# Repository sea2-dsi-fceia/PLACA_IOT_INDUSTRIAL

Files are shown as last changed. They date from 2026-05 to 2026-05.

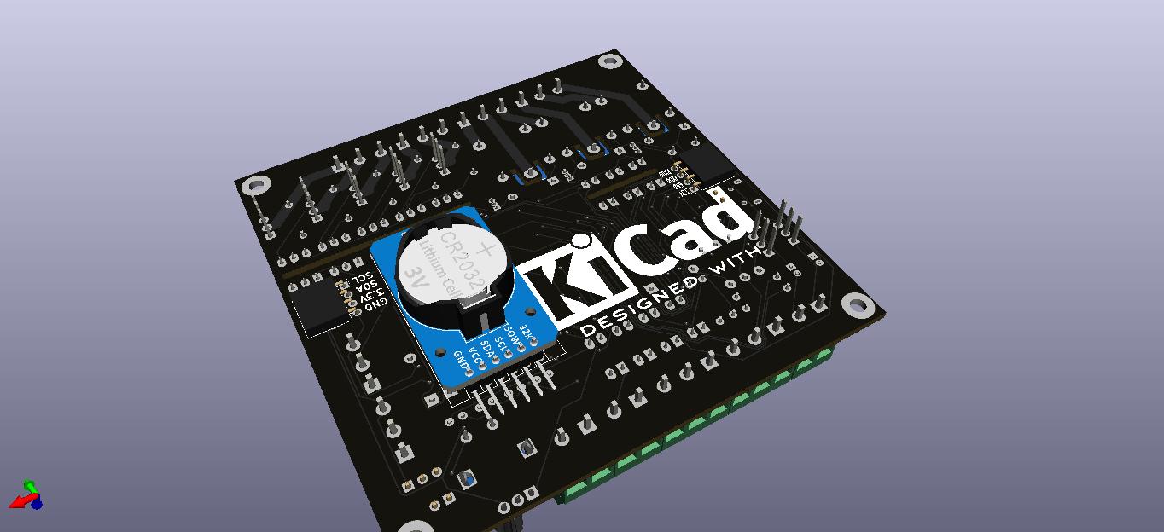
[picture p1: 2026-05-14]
Archivos_Kicad/Imagenes/PLC_ESP32_back.jpg

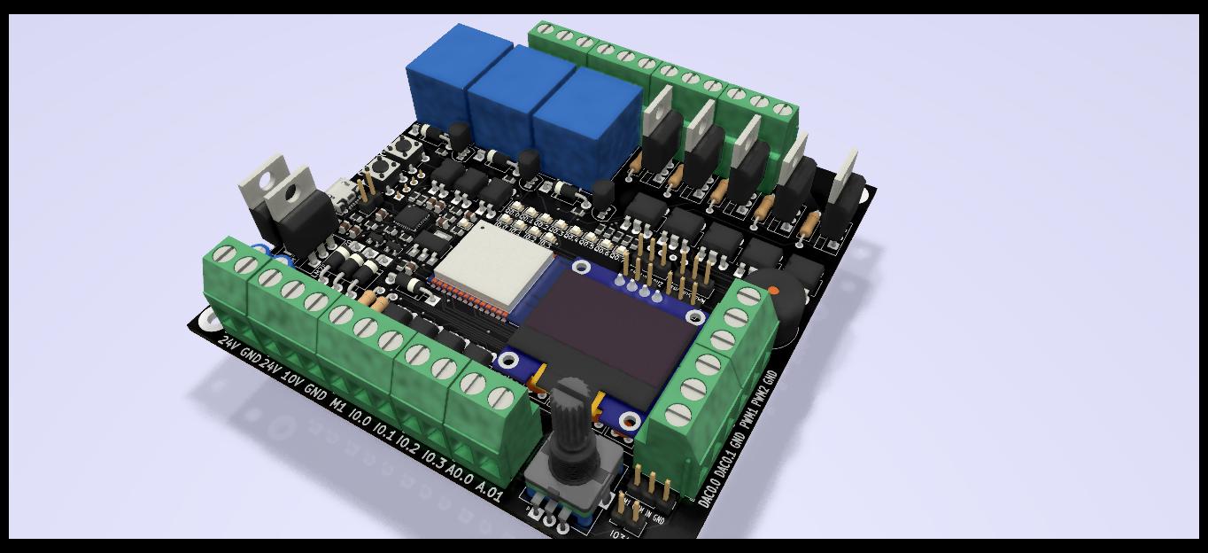
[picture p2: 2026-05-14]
Archivos_Kicad/Imagenes/PLC_ESP32.jpg

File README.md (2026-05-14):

## Placa de desarrollo IoT Industrial basada en ESP32
## 📝 Descripción
Este repositorio contiene el diseño y la documentación de una placa de desarrollo robusta diseñada para aplicaciones de Internet de las Cosas Industrial (IIoT), domótica y enseñanza de sistemas embebidos. El corazón del sistema es un microcontrolador ESP32 de Espressif, integrado en un hardware capaz de soportar entornos industriales exigentes. 
La placa permite gestionar lógica programada para actuar sobre cargas de potencia (electroválvulas, motores, actuadores) bajo condiciones específicas de trabajo.

## 🚀 Características Técnicas
### Alimentación y Entradas
- **Voltaje de alimentación:** Soporta niveles industriales entre 12V y 24V CC.  
- **Entradas Digitales (4):** Optoaisladas para protección del microcontrolador, con soporte de niveles entre 5V y 24V y LEDs testigos.
**NOTA:** Las entradas digitales deben tener configuradas en el ESP32 las resistencias de PULL-DOWN internas o agregar de forma externa resistencias de PULL-DOWN para que las etapas de entrada funcionen de forma correcta.
- **Entradas Analógicas (2):** Rango de 0V a 10V con alta impedancia. 

### Salidas de Potencia 
- **Salidas a Relé (3):** Relés de simple inversor optoaislados, con capacidad de manejo en 220V CA o 24V CC.  
- **Salidas de Estado Sólido (5):** Implementadas con TRIACs optoaislados (MOC3021 y BT136) para cargas de 220V CA. 
- **Protección:** Diodos de freewheeling (1N4007) en antiparalelo con las bobinas de los relés para proteger los transistores driver.

### Periféricos e Interfaz
- **Pantalla OLED:** Comandada por protocolo $I^{2}C$ para interfaz HMI local.  
- **Almacenamiento:** Memoria EEPROM para datos no volátiles.  
- **Tiempo Real:** Reloj calendario (RTC) con batería de backup para registro de eventos.  Indicadores: LED RGB y alarma sonora (buzzer) para monitoreo de estados.

## 🛠️ Diseño de Hardware
El PCB fue diseñado en KiCad priorizando la robustez y la facilidad de mantenimiento:
- **Aislamiento Galvánico:** Uso de optoacopladores PC817 para separar la lógica de las etapas de potencia.  
- **Seguridad Eléctrica:** Muescas de aislación en la placa alrededor de los conectores comunes de los relés para evitar arcos de voltaje en 220V CA.
- **Dimensionamiento:** Pistas trazadas en ambas capas (TOP y BOTTOM) para mejorar el manejo de corriente y evitar sobrecalentamiento.

## 💻 Desarrollo de Software
La placa es versátil en cuanto a paradigmas de programación:
- **Sistemas Operativos en Tiempo Real (RTOS):** Soporte nativo para FreeRTOS y Zephyr, garantizando tiempos de respuesta determinísticos ante eventos críticos.
- **Estándar Industrial:** Compatible con el proyecto OpenPLC, permitiendo programación en lenguaje Ladder bajo la norma IEC 61131-3.
- **Conectividad IIoT:** Implementación de protocolos como Modbus TCP, MQTT para telemetría, WebSockets y Webservers embebidos con interfaces HTML.  

## 📂 Ejemplo de Aplicación: Control de Caldera
El proyecto incluye un ejemplo integrador de un sistema de control de temperatura con seguridad por presión: 
- **Sensor:** Lectura de temperatura vía LM35 en entrada analógica.  
- **Seguridad:** Detección de alta presión mediante sensor digital que desactiva el calefactor y activa un ventilador de emergencia.  
- **Telemetría:** Monitoreo remoto mediante una webapp alojada en el propio microcontrolador.

## 📈 Roadmap y Mejoras Futuras
- Integración de puerto Ethernet nativo.  
- Implementación de buses de campo: RS-485 y CAN BUS.  
- Fuente de alimentación conmutada tipo Buck DC-DC para mayor eficiencia

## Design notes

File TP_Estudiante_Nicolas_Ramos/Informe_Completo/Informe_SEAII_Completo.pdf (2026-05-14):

## Universidad Nacional de Rosario

### Facultad de Ciencias Exactas, Ingeniería y Agrimensura

# Trabajo Práctico Integrador

Sistemas embebidos avanzados II

Alumno: RAMOS, Nicolás

Legajo: R-3892/1

Año: 2026

## Índice

### 1. Introducción

### 2. Validación de hardware placa de desarrollo

2.1 Objetivo y contexto

2.2 Descripción del hardware

2.3 Sketch de prueba

2.4 Herramientas de desarrollo

### 3. Etapa de modelado (UML)

3.1 Diagrama de casos de uso

3.2 Diagrama de actividad

3.3 Diagrama de despliegue

3.4 Diagrama de máquina de estados

3.5 Diagrama de componentes

3.6 Diagrama de secuencia

### 4. Etapa de implementación

4.1 Plataforma y herramientas

4.2 Estructura del proyecto y organización del código

4.3 Tareas y prioridades

4.4 Mecanismos de sincronización

4.5 Manejo de errores

4.6 Consideraciones de concurrencia

### 5. Conclusiones

### 6. Referencias y código fuente

4

## 1. Introducción

Este informe documenta de forma integrada el trabajo práctico desarrollado en la asignatura Sistemas Embebidos Avanzados II. El trabajo se organizó en dos etapas complementarias.

En la primera etapa se realizó el montaje de componentes sobre la placa de desarrollo para aplicaciones industriales IOT basada en ESP32 y la validación de hardware. El objetivo fue comprobar el correcto funcionamiento de entradas y salidas digitales, entradas analógicas, salidas DAC, display OLED, buzzer y periféricos asociados, antes de abordar el firmware más exigente en tiempo real.

En la segunda etapa se implementó un control de temperatura aplicado a una caldera, ejecutado sobre el sistema operativo en tiempo real FreeRTOS incluido en ESP-IDF. La información del proceso se presenta en un display OLED y en una página web servida por el propio microcontrolador, configurando el WiFi del ESP32 como punto de acceso (AP) para acceder sin depender de una red externa.

## 2. Validación de Hardware

### 2.1 Objetivo y contexto

El proyecto consistió en llevar a cabo el montaje de componentes, relevamiento del circuito esquemático y la validación de todas las etapas del circuito de forma individual. Una vez realizada dicha validación, se diseñó una plantilla para inicializar y configurar periféricos de la placa de desarrollo y una librería para el uso del display OLED, para ser usadas por futuros alumnos de la asignatura.

La placa incorpora periféricos útiles para automatización: entradas digitales y analógicas, salidas a relé y triacs, salidas PWM/DAC, display OLED por I²C, módulo RTC, buzzer y salidas de potencia. Para esta etapa se utilizó el IDE Arduino con el core ESP32, por la rapidez para compilar, flashear y probar cada recurso sin la sobrecarga inicial de un proyecto ESP-IDF completo.

5

### 2.2 Descripción del hardware

A continuación se resume la correspondencia entre recursos de la placa y GPIO del ESP32, coherente con el

sketch de validación PLC_ESP32_EntradasSalidas.ino.

### 2.2.1 Entradas digitales (I0.0 – I0.3)

Cuatro entradas digitales aisladas mediante optoacopladores, conectadas a GPIO del ESP32. En las pruebas se habilitaron pull-down internas.

Entrada | GPIO ESP32
I0.0 | 5
I0.1 | 15
I0.2 | 16
I0.3 | 34

Tabla 1 — Entradas digitales y GPIO.

### 2.2.2 Salidas digitales (Q0.0 – Q0.7)

Tres salidas a relés (Q0.0–Q0.2) y cuatro salidas a triacs (Q0.3–Q0.7), con etapas de acoplamiento.

Salida | GPIO ESP32
Q0.0 | 4
Q0.1 | 17
Q0.2 | 18
Q0.3 | 19

6

Salida | GPIO ESP32
Q0.4 | 23
Q0.5 | 27
Q0.6 | 32
Q0.7 | 33

Tabla 2 — Salidas digitales y GPIO.

### 2.2.3 Entradas analógicas (A0.0 – A0.1)

Entrada | GPIO
A0.0 | 36
A0.1 | 35

Tabla 3 — Entradas analógicas.

### 2.2.4 Salidas DAC (DAC0.0 – DAC0.1)

Salida | GPIO
DAC0.0 | 25
DAC0.1 | 26

Tabla 4 — Salidas DAC del ESP32.

### 2.2.5 Display OLED (I²C)

Display compatible con controlador SH1106, típicamente 128×64, dirección I²C 0x3C, SDA GPIO 21 y SCL

7

GPIO 22.

### 2.2.6 Buzzer y LED RGB

Buzzer en GPIO 2. LED RGB (cátodo común): R=14, G=13, B=12, según definiciones del sketch de validación.

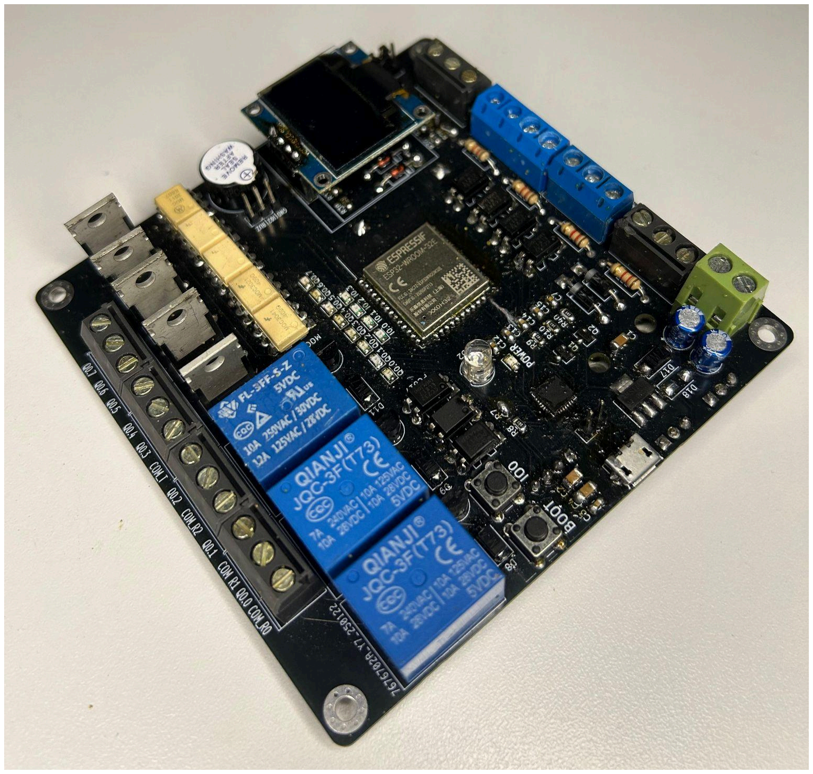
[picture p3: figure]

Figura 1. Placa de desarrollo para aplicaciones industriales IoT basada en ESP32

### 2.3 Sketch prueba de hardware

Con el programa de ejemplo se verificó, entre otros puntos:

- Entradas digitales I0.0–I0.3: lectura coherente en reposo y al activar cada entrada, con pull-down internas habilitadas.
- Entradas Analógicas A0.0–A0.1: lectura con analogRead y envío por puerto serie para correlacionar tensión aplicada (0–3,3 V) con el valor digital.
- Salidas digitales Q0.0–Q0.7: conmutación secuencial e individual; coherencia entre estado lógico y actuación sobre LED, relé o carga de prueba.

8

- Salidas DAC: uso de dacWrite y comprobación con multímetro.
- OLED: inicialización con librería Adafruit SH110X; texto y actualización periódica.
- Buzzer: conmutación periódica del pin para verificar audio; puede extenderse con tone().

### 2.4 Herramientas de desarrollo

- IDE Arduino con soporte ESP32, para el sketch PLC_ESP32_EntradasSalidas.ino.
- Cable USB y monitor serie para depuración y registro de valores analógicos.

## 3. Etapa de modelado (UML)

En esta parte del trabajo práctico se trabajó en un control de temperatura aplicado a una caldera, basado en sistema operativo en tiempo real, con varias actividades concurrentes, recursos compartidos y restricciones temporales.

Antes de escribir o integrar el firmware definitivo, se necesitó disponer de un modelo formal del sistema. Para ello, se utilizó como lenguaje común entre requisitos, diseño e implementación, el lenguaje UML (Unified Modeling Language). El modelado obliga a nombrar actores, límites del sistema, secuencias de interacción, estados discretos del control y piezas de software que deben coexistir bajo el planificador. A continuación se mostrarán los diagramas correspondientes para describir la lógica y dinámica del sistema, arquitectura del software y disposición del hardware.

9

### 3.1 Diagrama de casos de uso

El diagrama de casos de uso presenta el sistema embebido como una caja negra y enumera las capacidades visibles desde el exterior, sin entrar en tareas ni mutex. El límite del sistema (system boundary) encierra al controlador sobre la placa de desarrollo.

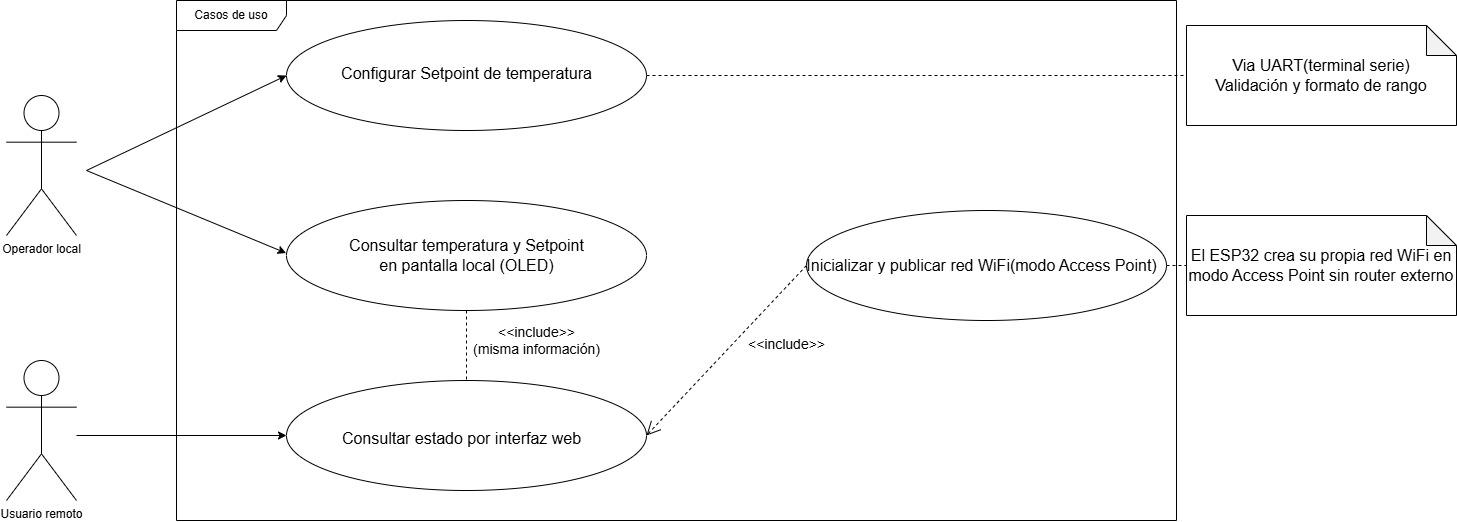
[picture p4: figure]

Figura 2. Diagrama Casos de Uso

10

### 3.2 Diagrama de actividad

El diagrama de actividad describe flujos de control con decisiones, bifurcaciones y actividades que pueden ser paralelas o secuenciales.

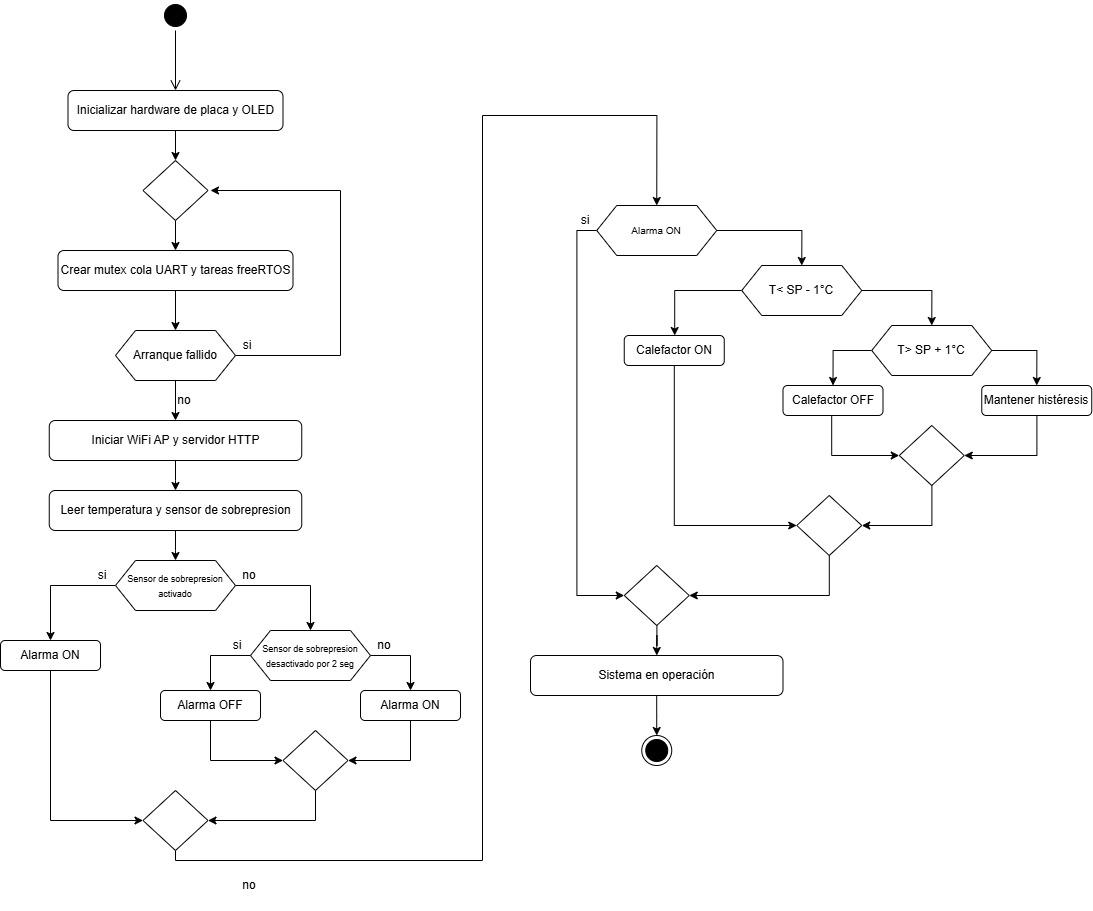
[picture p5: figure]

Figura 3. Diagrama de actividad

11

### 3.3 Diagrama de despliegue

Este diagrama se utiliza para modelar la arquitectura física de un sistema. Su objetivo principal es mostrar cómo se distribuyen los componentes de software en los recursos de hardware (como servidores, computadoras o dispositivos móviles) durante el tiempo de ejecución

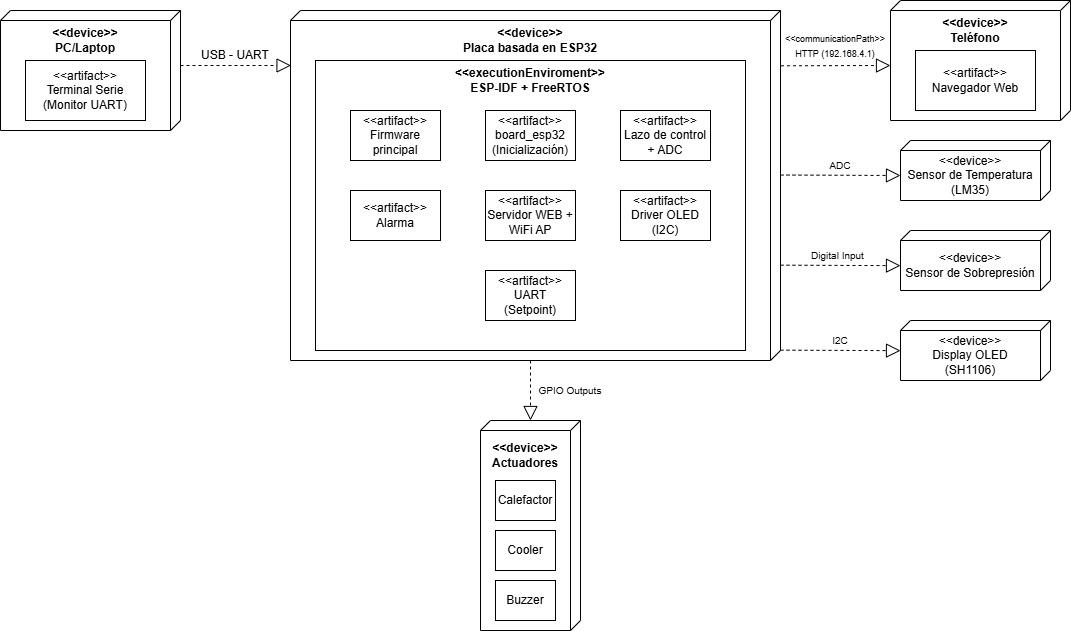
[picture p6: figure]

Figura 4. Diagrama de despliegue

12

### 3.4 Diagrama Máquinas de Estado

Este diagrama describe cómo se comporta un objeto específico o un sistema entero basándose en su historial de eventos. El sistema posee al menos dos estados lógicos dominantes: Normal y Alarma por sobrepresión. En Normal, la calefacción sigue una lógica con histéresis alrededor del setpoint y el cooler permanece desactivado salvo políticas adicionales no usadas aquí. En Alarma, la calefacción queda forzada a apagarse, el cooler se activa, el buzzer se activa de forma intermitente y las interfaces muestran un mensaje de advertencia.

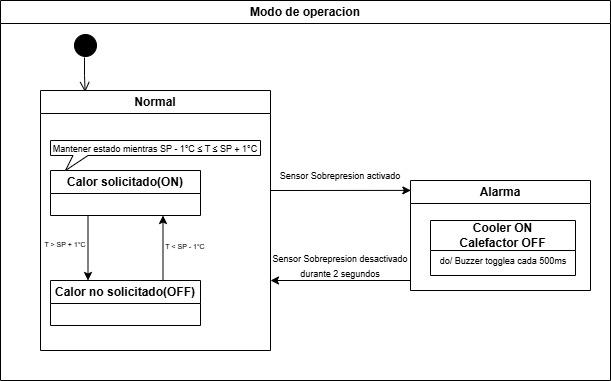
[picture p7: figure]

Figura 5. Diagrama de Máquinas de Estado

13

### 3.5 Diagrama de componentes

El diagrama de componentes muestra la arquitectura de software y las dependencias entre piezas, alineado con lo que luego se implementará como archivos y tareas.

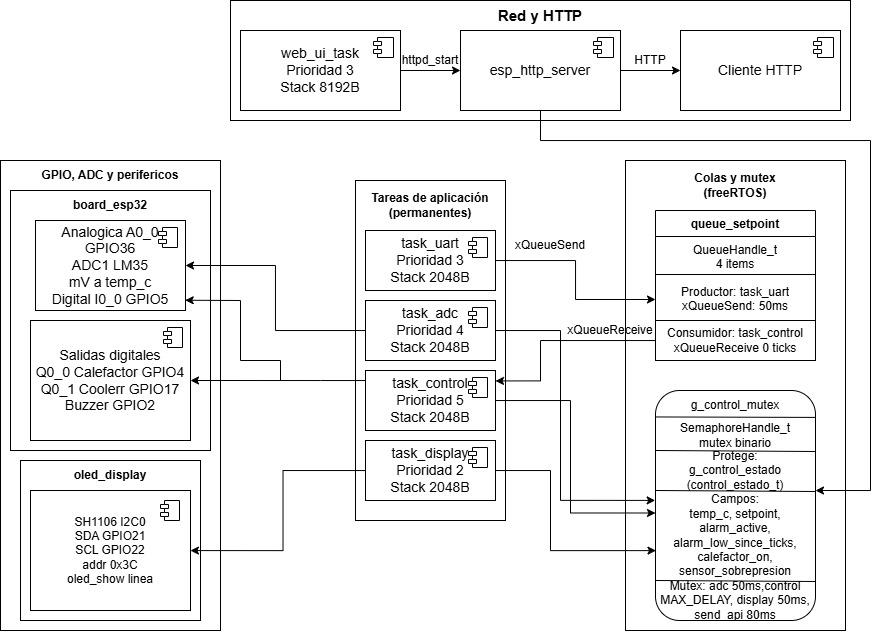
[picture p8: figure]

Figura 6. Diagrama de componentes

Entre estos componentes aparecen interfaces de FreeRTOS: una cola de mensajes para transportar enteros de setpoint desde la UART hacia el control; un mutex asociado a la estructura de estado compartido que deben

14 respetar la adquisición, el control, la vista OLED y el endpoint JSON. El diagrama debe mostrar que el servidor HTTP depende del mismo tipo de datos que la tarea de display, pero no debe dibujarse como si el HTTP escribiera directamente temperatura: en la implementación, el HTTP solo lee una copia bajo mutex. Las flechas de dependencia van desde las tareas o componentes de aplicación hacia los drivers de ESP-IDF (UART, GPIO, ADC, esp_wifi, esp_http_server), indicando que el firmware de aplicación se apoya en el framework.

### 3.6 Diagrama de secuencia

Es un diagrama de comportamiento que modela la interacción lógica entre objetos, enfocándose específicamente en el orden temporal en el que se intercambian mensajes para ejecutar una funcionalidad o escenario concreto. A diferencia de los diagramas estáticos (como el de clases de uso), este es dinámico: describe cómo "vive" y se comunica el sistema paso a paso durante un proceso.

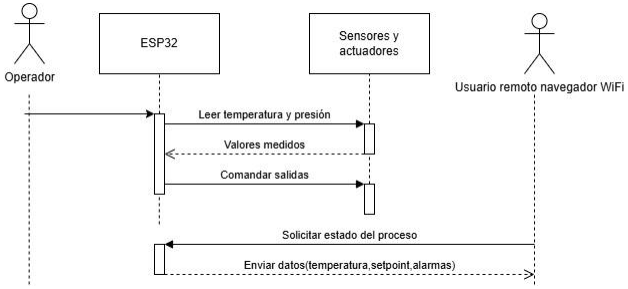
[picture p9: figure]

Figura 7. Diagrama de secuencia

15

## 4. Etapa de implementación

### 4.1 Plataforma y herramientas

La implementación del proyecto se basa en una placa de desarrollo equipada con el microcontrolador ESP32. Para su programación se utilizó el framework oficial del fabricante ESP-IDF, el cual integra el kernel del sistema operativo en tiempo real FreeRTOS y pone a disposición toda su API (tareas, colas, semáforos, mutex). El flujo de trabajo se gestionó a través del entorno Visual Studio Code con la extensión ESP-IDF, permitiendo compilar, flashear y monitorear el dispositivo por el puerto serial (UART0, vía USB). La UART0 queda reservada para la configuración del setpoint.

Para esta parte del trabajo práctico, se recurrió a la herramienta Cursor el cual es un entorno de programación basado en Visual Studio Code que integra asistencia con modelos de lenguaje (inteligencia artificial) para tareas como completar código, explicar fragmentos y apoyar la revisión de errores de compilación o de sintaxis. En ningún caso se delegó el criterio de diseño ni la responsabilidad del trabajo al asistente, el uso fue incremental y supervisado, es decir, se le indicaron objetivos concretos, se corrigió o descartó lo que no encajaba con el enunciado o con el hardware real, y se fue guiando el resultado (prioridades de tareas, sincronización con mutex y colas, comportamiento de alarmas, etc.) hasta alinearlo con lo implementado en el firmware y con lo exigido por la asignatura. Básicamente su uso sirvió para optimizar tiempos de codificación, por ejemplo en la estructuración de módulos y partes repetitivas del código, pero el contenido técnico, las decisiones y la verificación quedaron a mi cargo.

### 4.2 Estructura del proyecto y organización del código

El proyecto se organiza en módulos con responsabilidades bien definidas. A continuación presento los archivos y su función dentro del proyecto:

ESP32_FreeRTOS: Archivo principal del firmware. Contiene el punto de entrada app_main(), la definición de la estructura de estado compartido (estado_t), el mutex y la cola, las constantes de prioridad y tiempos, las

16 cuatro tareas: task_adc, task_uart, task_control, task_display, y web_ui_start(). Incluye además la función auxiliar leer_temperatura_lm35() que convierte la lectura del ADC a temperatura en °C.
board_esp32.c: Implementación de la capa de entradas/salidas. Configuración de GPIOs y ADC1.

board_esp32.h: Cabecera del módulo board_esp32. Define los números de GPIO para todas las entradas y salidas.

oled_display.c: Driver del display OLED SH1106 por I2C. Implementa inicialización del bus I2C (SDA y SCL), secuencia de inicio del SH1106, y las funciones oled. Utiliza una fuente 6×8 para mostrar texto centrado en una línea.

oled_display.h: Cabecera del módulo OLED. Define pines I2C, dirección del dispositivo (0x3C), dimensiones del display y declara las funciones públicas.

control_state.c: Implementación mínima del módulo. Inicializa g_control_estado con valores por defecto (setpoint, flags), aquí no se crea el mutex, sólo concentra el dato compartido del sistema.

control_state.h: Cabecera del estado compartido del control. Define el struct control_estado_t (temperatura, setpoint, alarma, flags y sobrepresión), y declara variables globales g_control_estado y el handle g_control_mutex para que las tareas y el HTTP las usen de forma coherente.

web_ui.c: Implementa el modo WiFi AP (NVS, netif, credenciales), arranca httpd con las rutas /html y el /api/status (JSON leyendo el estado bajo mutex) y crea la tarea web_ui_task que hace el init y luego se elimina mientras el servidor sigue activo.

web_ui.h: Cabecera del servidor web embebido. Declara la función de arranque web_ui_start para levantar el punto de acceso WiFi y el servidor HTTP.

### 4.3 Tareas y prioridades

Las tareas de aplicación son hasta cinco: cuatro se crean con xTaskCreate en app_main() (la de UART sólo si el driver instaló bien) y la quinta, web_ui_task, se crea dentro de web_ui_start() llamada desde app_main(). Las cuatro tareas periódicas corren en bucle infinito y ceden el CPU con vTaskDelay, mutex o cola/UART bloqueante; web_ui_task ejecuta la secuencia de arranque de red y HTTP y termina con vTaskDelete.

17

Tarea de adquisición de temperatura (task_adc)
Su función es mantener actualizado el valor de temperatura del proceso en la estructura de estado compartido, a partir de la lectura periódica del canal analógico A0.0 conectado al sensor LM35. No actúa sobre periféricos de salida, sólo escribe el campo temp_c del estado_t. En cada iteración la tarea intenta tomar el mutex con un timeout de 50 ms. Si lo obtiene, escribe la temperatura recién leída en estado.temp_c y libera el mutex de inmediato; en caso contrario omite la actualización en ese ciclo. A continuación ejecuta vTaskDelay(200 ms), con lo que cede el procesador y fija el período efectivo de muestreo en 200 ms.
La tarea se ejecuta en un bucle infinito. No mantiene estado local entre iteraciones más allá de la variable de temperatura leída. Ante fallo del ADC, leer_temperatura_lm35() retorna 0.0 °C, por lo que la tarea sigue actualizando el estado sin bloquear el sistema.

Tarea de recepción de setpoint por UART (task_uart)
Su función es encargarse de recibir por UART0 los setpoints que envía el operador desde un terminal o adaptador serial. Funciona en un bucle continuo y, en cada iteración, lee un solo byte de forma bloqueante (portMAX_DELAY), porque el enlace USB suele entregar los caracteres de a uno y leer bloques fijos de dos bytes no es fiable. Esos caracteres se van acumulando en un buffer interno hasta detectar un fin de línea (\r o \n). En ese momento se interpreta la línea: si contiene exactamente un dígito ASCII entre '0' y '9', el setpoint resultante es ese valor (0–9); si tiene al menos dos caracteres y los dos primeros son dígitos, se forma el número en decimal como decenas × 10 más unidades y se acota al rango 0–99 (valores mayores a 99 se consideran 99). Cualquier otra forma de línea al pulsar Enter no produce un envío a la cola. Cuando hay un setpoint válido, la tarea lo pone a disposición de task_control mediante xQueueSend sobre la cola de FreeRTOS, sin usar mutex, ya que la API de colas serializa de forma segura el paso de mensajes entre tareas. Si la cola está llena, la llamada espera como máximo 50 ms; si en ese intervalo no se pudo encolar, el intento falla, el valor de esa línea no se conserva para un reenvío posterior y la tarea sigue ejecutándose sin quedar bloqueada indefinidamente. La tarea no modifica el setpoint por defecto del sistema ni escribe directamente el estado compartido: solo aporta nuevos valores cuando el operador envía explícitamente una línea válida por UART0, y es task_control quien incorpora esos valores a partir de lo recibido por la cola.

18

Tarea de control (task_control)
Esta tarea concentra la lógica del lazo de temperatura y de la máquina de estados asociada a la sobrepresión leída en I0.0. En cada ciclo, primero intenta incorporar un nuevo setpoint desde la cola FreeRTOS con xQueueReceive y tiempo de espera nulo, de modo que no bloquee si no hay mensajes pendientes. A continuación toma el mutex g_control_mutex con portMAX_DELAY, es decir, espera el tiempo que haga falta hasta entrar en la sección crítica, y no hay un segundo bloqueo ni timeouts cortos dedicados al setpoint. Dentro de esa misma sección se lee la temperatura ya publicada en el estado global, se interpreta I0.0 según la polaridad configurada (PRESION_I0_ACTIVO_NIVEL_ALTO), se actualiza el indicador de alarma activa (entrada inmediata cuando la presión indica falla y salida solo tras 2000 ms continuos con I0.0 en el nivel “inactivo”), se escribe setpoint en el estado compartido para que la tarea de display y la interfaz web muestren el valor vigente, y se calcula el pedido de calefacción con histéresis respecto del setpoint, salvo en alarma, donde se anula la retención del calefactor. Tras xSemaphoreGive, fuera de la sección crítica, se aplican las salidas físicas: en alarma se apaga Q0.0(calefactor), se enciende Q0.1(cooler) y se hace togglear el buzzer con un período fijo; en operación normal se apagan cooler y buzzer y se activa Q0.0 según el resultado del control con histéresis. El ritmo del lazo queda acotado por vTaskDelay(100 ms) al final de cada iteración.

Tarea de presentación en display (task_display)
Esta tarea cumple una función exclusivamente de interfaz humano - máquina: pone a disposición del operador, en el display OLED, la información esencial del proceso, la temperatura medida, el setpoint vigente y la condición de alarma de sobrepresión. Cuando la alarma está activa, el mensaje se reduce a una leyenda fija de Sobrepresión; en operación normal se arma una cadena con temperatura y setpoint y se envía al driver del OLED. Para obtener esos datos sin mezclar lecturas parciales con escrituras concurrentes de otras tareas, la rutina toma el mutex con un timeout de 50 ms, copia en variables locales la temperatura, el setpoint y el flag de alarma, y libera de inmediato el mutex. Ejecuta el trabajo más lento —formateo de texto y actualización del display vía I2C— fuera de la sección crítica, lo que mantiene acotado el tiempo en que el mutex está tomado y reduce la interferencia con tareas que actualizan el mismo estado global. Si en un ciclo no se consigue el mutex dentro del plazo de espera, la tarea no refresca el OLED en esa pasada, aplica un vTaskDelay de 200

19 ms y vuelve a intentar en la siguiente vuelta del bucle, evitando bloqueos indefinidos. Tras una actualización exitosa del display, el ritmo queda marcado por un vTaskDelay de 500 ms, de modo que la presentación se renueva aproximadamente dos veces por segundo. La tarea no modifica el estado del control ni las salidas de campo; se limita a leer el estado compartido y a reflejarlo en pantalla.

Tarea de interfaz web (web_ui_task)
Es la encargada de poner en marcha la interfaz web del proyecto. Se crea desde web_ui_start() con prioridad 3 y un stack de 8192 Bytes, pensada para absorber el consumo de memoria del init de WiFi en modo punto de acceso (NVS, esp_netif, bucle de eventos, configuración del AP con SSID y contraseña fijos) y la creación del servidor HTTP del ESP-IDF. En la práctica, la rutina inicializa el AP, espera 500 ms para dejar estabilizar la interfaz de red y llama a httpd_start, registrando dos URL: la raíz que sirve la página HTML embebida con estilos y un script que consulta periódicamente el estado, y /api/status, que responde en JSON con temperatura, setpoint, estado del calefactor, lectura lógica de sobrepresión y bandera de alarma. El handler de la API toma el mutex con un timeout de 80 ms, copia la estructura g_control_estado a una variable local y libera el mutex antes de formatear y enviar la respuesta; si el mutex no está disponible a tiempo, devuelve 503(servicio no disponible) con un cuerpo mínimo, evitando bloquear indefinidamente al cliente y evitando servir datos inconsistentes. Al terminar el arranque, la tarea se autoelimina con vTaskDelete(NULL), el portal sigue atendido por las tareas internas del stack HTTP de Espressif, mientras que web_ui_task ya no permanece en un bucle periódico como las tareas de ADC, control o display.
TAREA | PRIORIDAD | PERIODO O CONDICIÓN | STACK
task_control | 5 | Cada 100 ms | 2048B
task_adc | 4 | Cada 200 ms | 2048B
task_uart | 3 | Bloqueada en uart_read_bytes hasta recibir un carácter (portMAX_DELAY) | 2048B
task_display | 2 | Cada 500 ms | 2048B

20

web_ui_task | 3 | Un solo arranque: WiFi AP + httpd_start, luego vTaskDelete (no periódica)”.

8192B

### 4.4 Mecanismos de sincronización

Estructura de estado compartido
- La variable global es g_control_estado, de tipo control_estado_t. typedef struct {
float | temp_c; /* Temperatura medida en °C*/
int | setpoint; /*Consigna en °C*/
bool | alarm_active; /*Estado alarma*/
TickType_t alarm_low_since_ticks; /*Marca de ticks con I0.0 activada para salir de modo Alarma*/
bool | calefactor_on;
bool | sensor_sobrepresion;
} control_estado_t;
- task_adc escribe sólo temp_c.
- task_control lee temp_c y el estado de alarma. Actualiza alarm_active, alarm_low_since_ticks, setpoint, calefactor_on y sensor_sobrepresion.
- task_display sólo lee temp_c, setpoint y alarm_active para el OLED.
- El handler send_api en web_ui.c copia bajo mutex toda la estructura a una variable local st de tipo control_estado_t para armar el JSON.

Todo acceso a g_control_estado debe realizarse con el mutex tomado.

Mutex (g_control_mutex)
El mutex actúa como candado, sólo una tarea puede poseerlo a la vez.
Uso: xSemaphoreTake(g_control_mutex, timeout) → acceso a g_control_estado → xSemaphoreGive(g_control_mutex).

21

Timeouts: 50 ms (task_adc, task_display), portMAX_DELAY (task_control) y 80 ms en send_api(si no obtiene el mutex, responde 503).

Cola (queue_setpoint)
Es un buffer FIFO de FreeRTOS que transporta setpoints como enteros int en el rango 0–99 (tras la validación en task_uart) desde task_uart hasta task_control, sin que la UART escriba directamente en g_control_estado.

Se declara como QueueHandle_t estático en ESP32_FreeRTOS.c y se crea con xQueueCreate(SETPOINT_QUEUE_LEN, sizeof(int)), donde SETPOINT_QUEUE_LEN vale 4: hasta cuatro mensajes pendientes.

task_uart: envía con xQueueSend(queue_setpoint, &setpoint, pdMS_TO_TICKS(50)). Si la cola está llena, espera como máximo 50 ms; si en ese plazo no pudo encolar, ese valor no se guarda para un reintento automático.

task_control: al inicio de cada ciclo hace xQueueReceive(queue_setpoint, &nuevo_setpoint, 0), el 0 indica sin espera, es decir no bloqueante.Si no hay mensaje nuevo, sigue con el setpoint local que ya tenía.

Las operaciones xQueueSend / xQueueReceive sobre la misma cola están pensadas para uso concurrente entre tareas en FreeRTOS: el kernel serializa el acceso a la cola, de modo que no hace falta un mutex adicional solo para encolar o desencolar el setpoint entre task_uart y task_control.

22

### 4.5 Manejo de errores

SITUACIÓN | DÓNDE SE DETECTA | ACCIÓN | EFECTO
Fallo al crear mutex (g_control_mutex) o cola (queue_setpoint) | app_main() tras xSemaphoreCreateMutex() / xQueueCreate() | return (sin log en ese if) | No se ejecutan xTaskCreate ni web_ui_start(): el lazo de tareas no arranca.
Fallo uart_driver_install en UART0 (USB, setpoint) | app_main() | No se llama xTaskCreate(task_uart, …); el resto de tareas sí se crean | No hay entrada de setpoint por terminal; task_control mantiene SETPOINT_DEFAULT (25 °C) hasta otra vía.
Fallo al crear unidad ADC1 | board_esp32_init() (adc_oneshot_new_unit ≠ ESP_OK) | adc1_handle = NULL | board_esp32_adc_a0_0 _mv() devuelve -1; leer_temperatura_lm35() puede quedar con n = 0 y devuelve 0.0 °C; el lazo puede reaccionar mal si se interpreta como “muy frío”.
Fallo calibración ADC | board_esp32_init() (adc_cali_create_scheme_line_f itting ≠ ESP_OK) | adc1_cali_a0 = NULL | Sigue habiendo lectura por conversión aproximada raw→mV; peor precisión, no bloquea el arranque.
Cola queue_setpoint llena al enviar setpoint | task_uart en xQueueSend(..., pdMS_TO_TICKS(50)) | El resultado se ignora con (void) | Ese setpoint se pierde; el operador debe reenviar el comando.
Timeout al tomar g_control_mutex (50 ms) | task_adc | No escribe g_control_estado.temp_c en ese ciclo | La temperatura mostrada/controlada puede quedar desactualizada hasta el próximo ciclo exitoso.

23

Timeout al tomar g_control_mutex (50 ms) | task_display | vTaskDelay(200 ms) y continue | No se actualiza el OLED en esa pasada; reintento después del delay.
g_control_mutex nulo o timeout (80 ms) al tomar mutex | send_api (web_ui.c) | Responde 503 | El navegador no recibe JSON de estado en esa petición (el script puede dejar valores viejos).
Fallo I2C en init del OLED | oled_display_init() | return antes de marcar éxito; oled_initialized permanece false (sin ESP_LOGE en esas líneas) | Display inoperativo hasta que otra llamada (p. ej. oled_show) reintente oled_display_init().
Fallo httpd_start | http_start() en web_ui.c | ESP_LOGE y return sin registrar URI | WiFi AP puede estar activo pero sin página / ni API /api/status útiles.
Fallos en init WiFi/NVS con ESP_ERROR_CHECK | wifi_init_ap() en web_ui.c | En IDF suele abortar el programa con mensaje de error | Reinicio o detención según configuración del proyecto; no es un fallo “silencioso” como el return de app_main.

### 4.6 Consideraciones de concurrencia

En este firmware varias actividades compiten por los mismos datos y recursos: las tareas task_adc, task_control y task_display, junto con los handlers HTTP del servidor en web_ui, pueden ejecutarse de forma entrelazada según el scheduler de FreeRTOS. Para evitar esto, todas las lecturas y escrituras de g_control_estado pasan por el mismo mutex g_control_mutex, con tiempos de espera acotados donde la interfaz puede ceder (50 ms en ADC y display, 80 ms en la API) y portMAX_DELAY en task_control, priorizando que el lazo y la lógica de alarma sigan actualizándose de forma predecible. El setpoint que llega

24 por UART no se escribe directamente en el estado compartido: task_uart solo encola enteros en queue_setpoint, y task_control los consume sin bloquear (xQueueReceive con espera cero), de modo que la recepción y validación del setpoint por UART0 no retiene el mutex ni prolonga la sección crítica del control. Las salidas físicas (GPIO de relés, cooler y buzzer) se actualizan después de liberar el mutex, reduciendo el tiempo en que otras tareas quedan bloqueadas esperando el mutex mientras se completan escrituras lentas a hardware. Las operaciones sobre la cola usan la API thread-safe del kernel, sin mutex adicional entre productor y consumidor del setpoint. Conviene tener presente que misma prioridad (por ejemplo task_uart y web_ui_task con prioridad 3) implica reparto por round-robin(se alternan), y que un handler HTTP que tardara demasiado podría retrasar a otras tareas de igual prioridad; el diseño actual limita el trabajo bajo mutex a copias breves de estructura y deja el formato JSON fuera de la sección crítica para mitigar ese riesgo.

25

## 5. Conclusiones

Este trabajo práctico atravesó las etapas típicas del desarrollo de un sistema embebido: primero con el montaje en PCB y validación de hardware se pudo asegurar el correcto funcionamiento de la placa, de modo que los problemas posteriores durante la implementación de software sean atribuidos a dicha etapa y no a fallas de cableado o periféricos.
A partir de este punto, la segunda parte, comenzando por el modelado con UML, ayudó a ordenar actores, responsabilidades, flujos de datos y estados, antes de comenzar con la programación propiamente dicha. Eso redujo ambigüedades sobre quien lee o escribe, temperatura, setpoint, alarma y salidas, y cómo se relacionan el operador, la UART, el display, la web y el lazo de control. En la implementación, esas decisiones se tradujeron en un diseño con varias tareas y prioridades, mutex sobre un estado compartido, y cola para el setpoint, además de temporizaciones y políticas de error acotadas. Se consolidó así la idea de concurrencia segura, donde el scheduler puede intercalar tareas, pero el acceso ordenado a datos y el paso de mensajes evitan condiciones de carrera y acoplamientos frágiles entre módulos.

Otro aprendizaje fue entender el uso del freeRTOS frente a bare-metal: en éste suele predominar un bucle principal e interrupciones, lo que complica atender tareas que deben ejecutarse con frecuencias distintas (muestreo, control, interfaz, red) sin que una parte bloquee otras y empuja a un estado global difícil de mantener. Con freeRTOS, la aplicación se organiza en tareas concurrentes con su período o bloqueo en E/S, el handler reparte el CPU según prioridad, y primitivas como mutex y colas estructuran al paralelismo lógico. El costo es mayor complejidad conceptual (sincronización, stacks, depuración de interacciones), pero el beneficio es un firmware más modular, escalable y alineado con sistemas industriales reales donde conviven control, comunicación e interfaz.

Por último, el uso de herramientas como Cursor resultó práctico para acelerar tiempos de codificación y corregir errores de sintaxis, pero no sustituye de ninguna manera el criterio del alumno, hubo que supervisar y rectificar constantemente nombres, tiempos, salidas incorrectas, asignaciones de prioridades, entre otras cosas. En un trabajo de ingeniería, la IA es una herramienta auxiliar, pero la responsabilidad del modelo, de la implementación y de la coherencia entre ambos sigue siendo del equipo que desarrolla y valida el sistema.

26

## 6. Referencias y código fuente

1. Espressif Systems. ESP-IDF Programming Guide. Documentación oficial ESP-IDF (build, FreeRTOS, WiFi, HTTP server). https://docs.espressif. com/projects/esp-modbus/en/latest/esp32/
2. FreeRTOS. Mastering the FreeRTOS Real Time Kernel — referencia de planificación, mutex, colas y buenas prácticas. https://www.freertos.org/Documentation/02-Kernel/07-Books-and-manual/01-RTOS_book.
3. Repositorio Proyecto_Final (archivos ESP32_FreeRTOS.c, web_ui.c, board_esp32.c, oled_display.c, control_state.c). https://github.com/nicojramos/Trabajo_Integrador_SEAII
4. UML-Diagrams.org, “Uml diagrams reference.” https://www.uml-diagrams.org/.

27

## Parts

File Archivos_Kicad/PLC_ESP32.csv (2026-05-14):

Reference | Quantity | Value | Footprint | Datasheet
BZ1 | 1 | Buzzer | Buzzer_Beeper:Buzzer_12x9.5RM7.6 | ~
C10 | 1 | 0.33uf | Capacitor_THT:CP_Radial_D5.0mm_P2.00mm | ~
C11 | 1 | 0.1uf | Capacitor_THT:CP_Radial_D5.0mm_P2.00mm | ~
C12 C13 C14 C15 | 4 | 100nf | Capacitor_THT:C_Disc_D5.0mm_W2.5mm_P2.50mm | ~
C2 | 1 | 47uf/6.3V(10%) | Capacitor_SMD:C_0805_2012Metric | ~
C3 C8 C9 C7 C5 | 5 | 0.1uf/50V(10%) | Capacitor_SMD:C_0805_2012Metric | ~
C4 C1 C6 | 3 | 22uF/10V(20%) | Capacitor_SMD:C_0805_2012Metric | ~
D1 | 1 | LED RED | LED_THT:LED_D3.0mm | ~
D19 D20 D22 D24 | 4 | LED | LED_THT:LED_D3.0mm | ~
D2 D3 D4 | 3 | LESD5D5.0CT1G |  | ~
D21 D23 | 2 | 1N4728A/3.3V | Diode_THT:D_DO-41_SOD81_P10.16mm_Horizontal | https://www.vishay.com/docs/85816/1n4728a.pdf
D5 | 1 | BAT760-7 30V 1A | Diode_THT:D_DO-41_SOD81_P10.16mm_Horizontal | ~
D6 D7 D10 D13 D14 D15 D16 D12 | 8 | LED | LED_SMD:LED_0805_2012Metric | ~
D8 D9 D11 D17 D18 | 5 | 1N4007 | Diode_THT:D_DO-41_SOD81_P10.16mm_Horizontal | http://www.vishay.com/docs/88503/1n4001.pdf
J1 | 1 | USB_B_Micro | BorneraTornillos:Conn_USBmicro-B_ebay-side_TH | ~
J10 | 1 | Salidas Analogicas | BorneraTornillos:TerminalBlock_Phoenix_PT-1,5-3-5.0-H_1x03_P5.00mm_Horizontal | ~
J11 | 1 | Salida PWM | BorneraTornillos:TerminalBlock_Phoenix_PT-1,5-3-5.0-H_1x03_P5.00mm_Horizontal | ~
J12 | 1 | UART_SERIE | Connector_PinSocket_2.54mm:PinSocket_1x04_P2.54mm_Vertical | ~
J13 J14 | 2 | Entrada Digital | BorneraTornillos:TerminalBlock_Phoenix_PT-1,5-3-5.0-H_1x03_P5.00mm_Horizontal | ~
J15 | 1 | Entrada Digital | BorneraTornillos:TerminalBlock_Phoenix_PT-1,5-2-5.0-H_1x02_P5.00mm_Horizontal | ~
J16 | 1 | Entrada Analogica | BorneraTornillos:TerminalBlock_Phoenix_PT-1,5-2-5.0-H_1x02_P5.00mm_Horizontal | ~
J2 J3 | 2 | Terminales Reles | BorneraTornillos:TerminalBlock_Phoenix_PT-1,5-3-5.0-H_1x03_P5.00mm_Horizontal | ~
J4 J5 | 2 | Terminales Triacs | BorneraTornillos:TerminalBlock_Phoenix_PT-1,5-3-5.0-H_1x03_P5.00mm_Horizontal | ~
J6 | 1 | Entrada_24VDC | BorneraTornillos:TerminalBlock_Phoenix_PT-1,5-2-5.0-H_1x02_P5.00mm_Horizontal | ~
J7 | 1 | PANTALLA LCD I2C | Connector_PinSocket_2.54mm:PinSocket_1x04_P2.54mm_Horizontal | ~
J8 | 1 | DS3231 | BorneraTornillos:DS3231_Shield | ~
J9 | 1 | PANTALLA OLED | Connector_PinSocket_2.54mm:PinSocket_1x04_P2.54mm_Vertical | ~
JP1 | 1 | Habilitacion VBUS | Connector_PinHeader_2.54mm:PinHeader_1x02_P2.54mm_Vertical | ~
JP2 | 1 | Comun Entradas | Connector_PinHeader_2.54mm:PinHeader_1x03_P2.54mm_Vertical | ~
K1 K2 K3 | 3 | SANYOU_SRD_Form_C | Relay_THT:Relay_SPDT_SANYOU_SRD_Series_Form_C | http://www.sanyourelay.ca/public/products/pdf/SRD.pdf
Q1 Q2 | 2 | SS8050-G | Package_TO_SOT_THT:TO-126-3_Vertical | http://www.st.com/internet/com/TECHNICAL_RESOURCES/TECHNICAL_LITERATURE/DATASHEET/CD00001225.pdf
Q3 Q4 Q5 | 3 | 2N2222A | Package_TO_SOT_THT:TO-92_Inline | http://www.fairchildsemi.com/ds/BC/BC547.pdf
Q7 Q8 Q9 Q10 Q6 | 5 | BT136-500 | Package_TO_SOT_THT:TO-220-3_Vertical | http://www.micropik.com/PDF/BT136-600.pdf
R11 R12 R15 R18 R19 R23 R24 R17 | 8 | 45/ 1/8W (5%) | Resistor_SMD:R_0805_2012Metric | ~
R13 R14 R16 | 3 | 2K | Resistor_SMD:R_0805_2012Metric | ~
R2 | 1 | 22.1K(5%) | Resistor_SMD:R_0805_2012Metric | ~
R21 R22 R25 R26 R20 | 5 | 33K | Resistor_THT:R_Axial_DIN0207_L6.3mm_D2.5mm_P10.16mm_Horizontal | ~
R27 R31 R36 | 3 | 1K/0.5W (5%) | Resistor_THT:R_Axial_DIN0207_L6.3mm_D2.5mm_P10.16mm_Horizontal | ~
R28 R32 | 2 | 1K/ 1/8W (5%) | Resistor_SMD:R_0805_2012Metric | ~
R3 | 1 | 47.5K(5%) | Resistor_SMD:R_0805_2012Metric | ~
R30 R35 | 2 | 2K/ 1/8W (5%) | Resistor_SMD:R_0805_2012Metric | ~
R33 | 1 | 1K/0.5W (5%) | Resistor_THT:R_Axial_DIN0207_L6.3mm_D2.5mm_P7.62mm_Horizontal | ~
R37 R38 | 2 | 2K2 (5%) | Resistor_SMD:R_0805_2012Metric | ~
R4 R1 | 2 | 2K(5%) | Resistor_SMD:R_0805_2012Metric | ~
R5 R8 R9 R10 | 4 | 10K(5%) | Resistor_SMD:R_0805_2012Metric | ~
R6 R7 | 2 | 0R(5%) | Resistor_SMD:R_0805_2012Metric | ~
SW1 SW2 | 2 | SW_Push | Button_Switch_THT:SW_PUSH_6mm | ~
U1 | 1 | AMS1117-3.3 | Package_TO_SOT_SMD:SOT-223-3_TabPin2 | http://www.advanced-monolithic.com/pdf/ds1117.pdf
U12 | 1 | LM7805_TO220 | Package_TO_SOT_THT:TO-220-3_Vertical | http://www.fairchildsemi.com/ds/LM/LM7805.pdf
U13 | 1 | LM7810_TO220 | Package_TO_SOT_THT:TO-220-3_Vertical | http://www.fairchildsemi.com/ds/LM/LM7805.pdf
U15 | 1 | LM358 | Package_DIP:DIP-8_W7.62mm_SMDSocket_SmallPads | http://www.ti.com/lit/ds/symlink/lm2904-n.pdf
U2 | 1 | CP2102N-A01-GQFN28 | Package_DFN_QFN:QFN-28-1EP_5x5mm_P0.5mm_EP3.35x3.35mm | https://www.silabs.com/documents/public/data-sheets/cp2102n-datasheet.pdf
U3 | 1 | ESP32-WROOM-32 | RF_Module:ESP32-WROOM-32 | https://www.espressif.com/sites/default/files/documentation/esp32-wroom-32_datasheet_en.pdf
U4 U5 U6 U14 U16 U17 U18 | 7 | PC817 | Package_DIP:DIP-4_W7.62mm_LongPads | http://www.soselectronic.cz/a_info/resource/d/pc817.pdf
U8 U9 U10 U11 U7 | 5 | MOC3021M | Package_DIP:DIP-6_W7.62mm_LongPads | http://www.fairchildsemi.com/ds/MO/MOC3020M.pdf

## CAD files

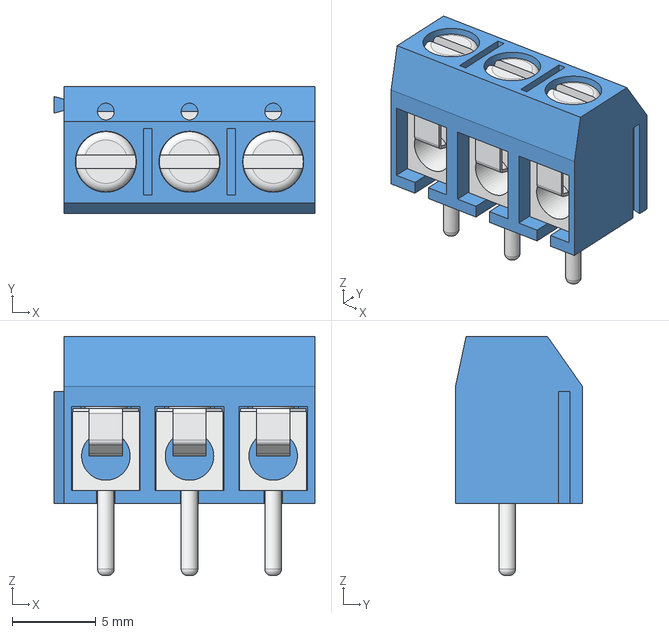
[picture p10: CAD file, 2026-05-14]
Archivos_Kicad/Modelos 3d/DG301-5.0-03.stp
15.6 x 7.60 x 14.3 mm

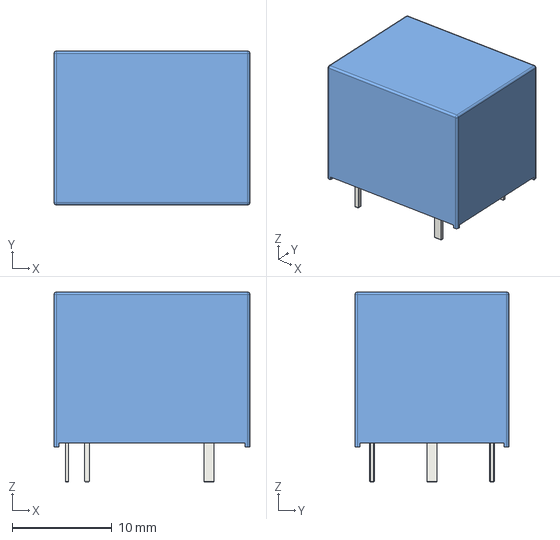
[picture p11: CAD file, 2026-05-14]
Archivos_Kicad/Modelos 3d/Relay_SPDT_SANYOU_SRD_Series_Form_C.step
19.6 x 15.4 x 19.0 mm

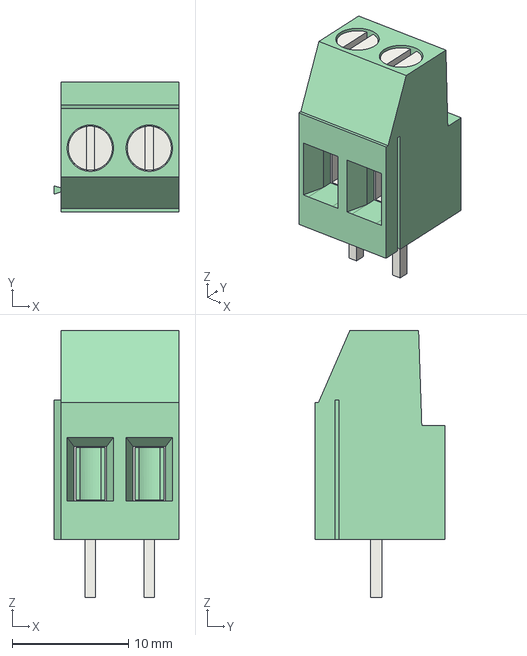
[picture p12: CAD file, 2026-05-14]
Archivos_Kicad/Modelos 3d/TerminalBlock_Phoenix_MKDS-3-2-5.08_1x02_P5.08mm_Horizontal.step
10.7 x 11.2 x 23.0 mm

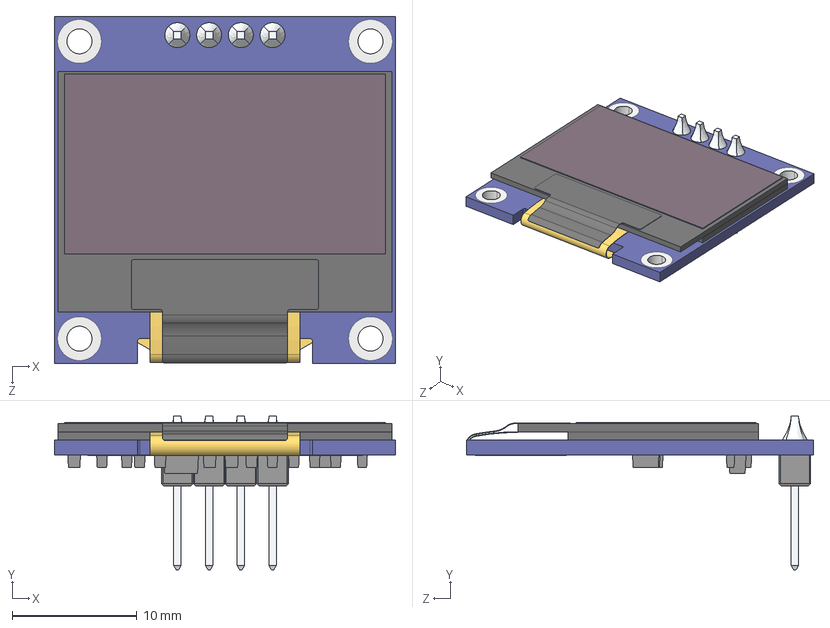
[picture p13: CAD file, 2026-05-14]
Archivos_Kicad/Modelos 3d/OLED TFT 0.96 inch 64x128 monochrome.STEP
27.3 x 12.3 x 27.8 mm

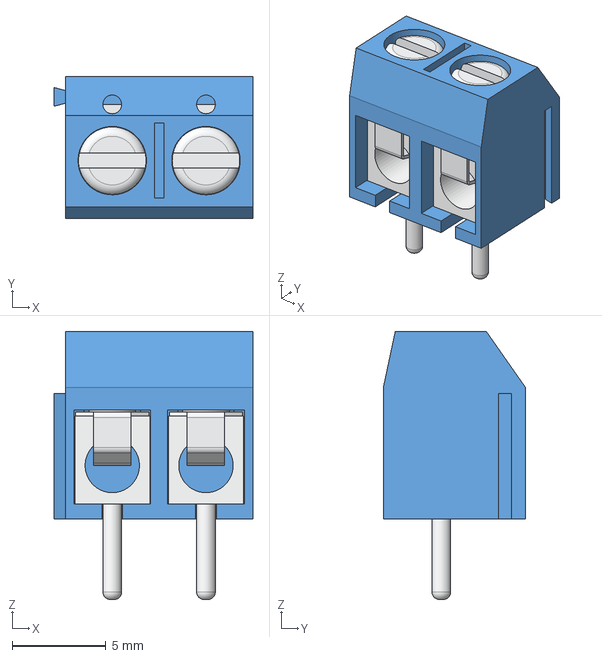
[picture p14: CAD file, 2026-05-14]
Archivos_Kicad/Modelos 3d/DG301-5.0-02.stp
10.6 x 7.60 x 14.3 mm

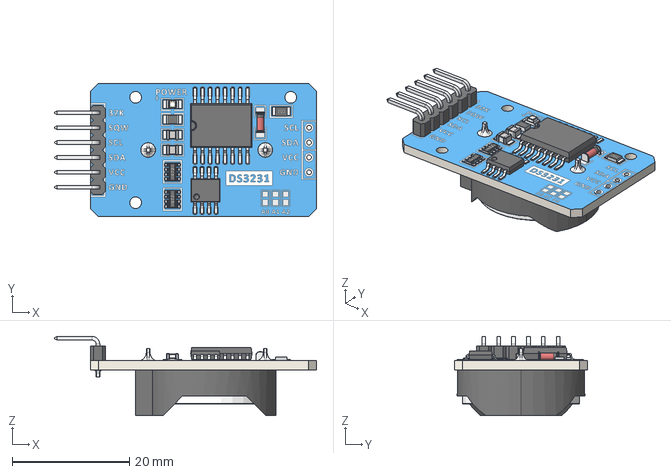
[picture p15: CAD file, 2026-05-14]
Archivos_Kicad/Modelos 3d/DS3231 RTC.step
44.8 x 22.8 x 13.5 mm

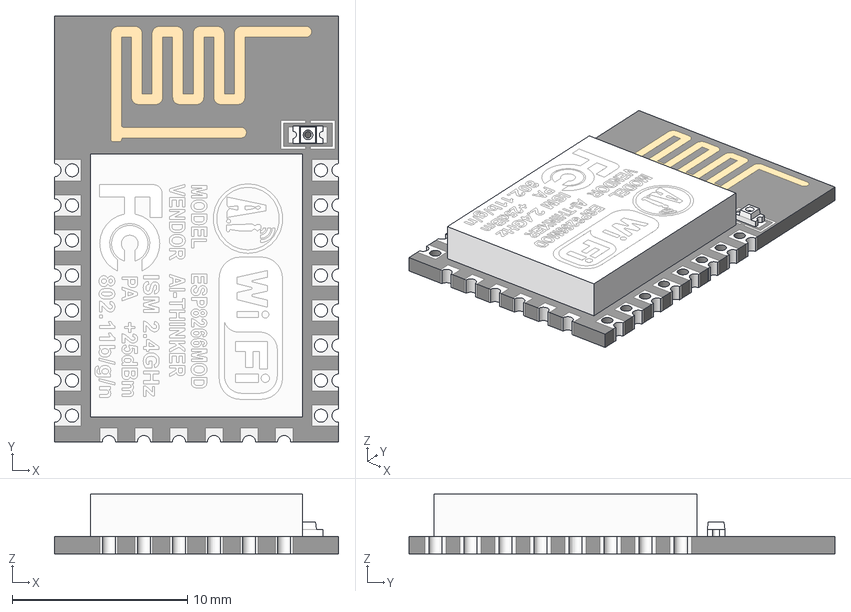
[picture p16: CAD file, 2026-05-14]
Archivos_Kicad/Modelos 3d/ESP-12-E-better.step
16.2 x 24.3 x 3.40 mm

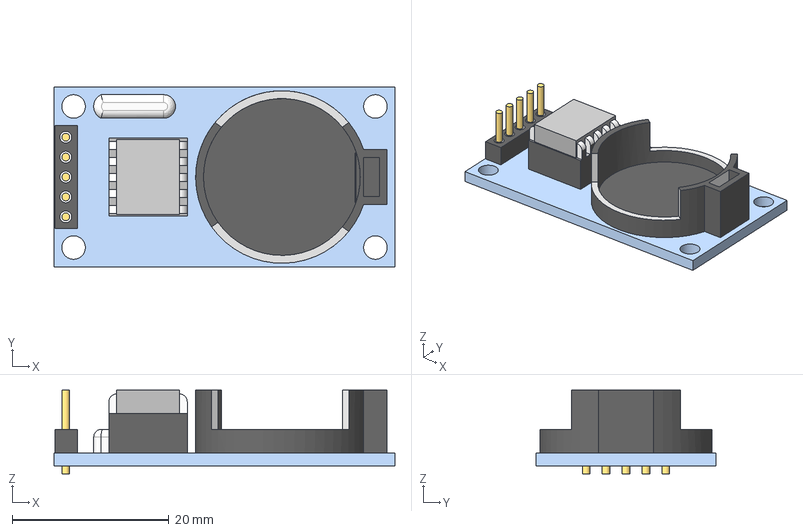
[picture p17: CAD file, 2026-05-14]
Archivos_Kicad/Modelos 3d/REAL_TIME_SHEELD.stp
43.5 x 23.0 x 10.7 mm

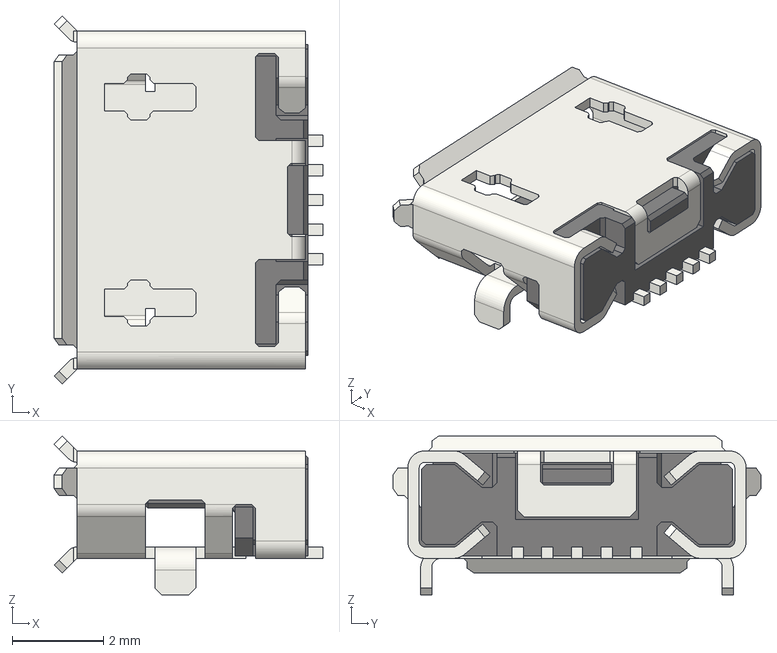
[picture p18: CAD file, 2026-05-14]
Archivos_Kicad/Modelos 3d/Conn_USB-micro-2.0_socket_right-angle.step
5.88 x 8.05 x 3.47 mm

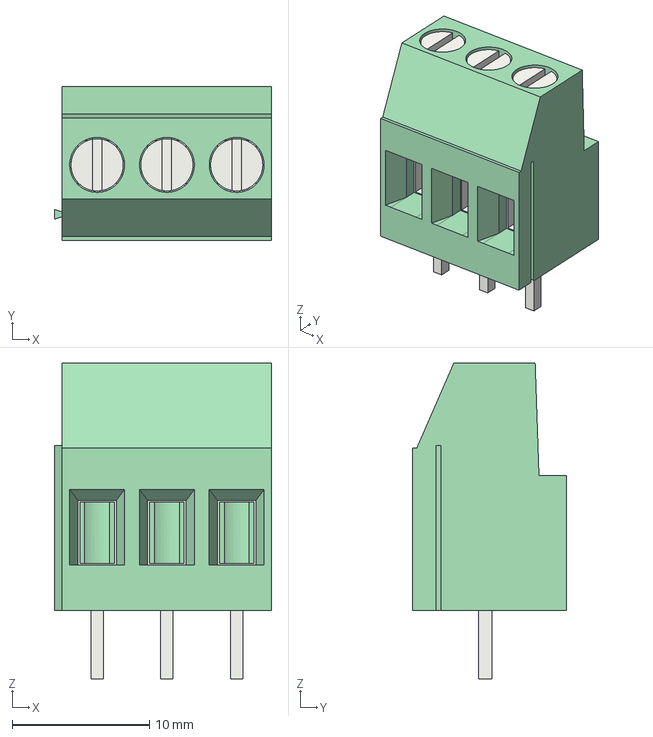
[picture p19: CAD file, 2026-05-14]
Archivos_Kicad/Modelos 3d/TerminalBlock_Phoenix_MKDS-3-3-5.08_1x03_P5.08mm_Horizontal.step
15.8 x 11.2 x 23.0 mm

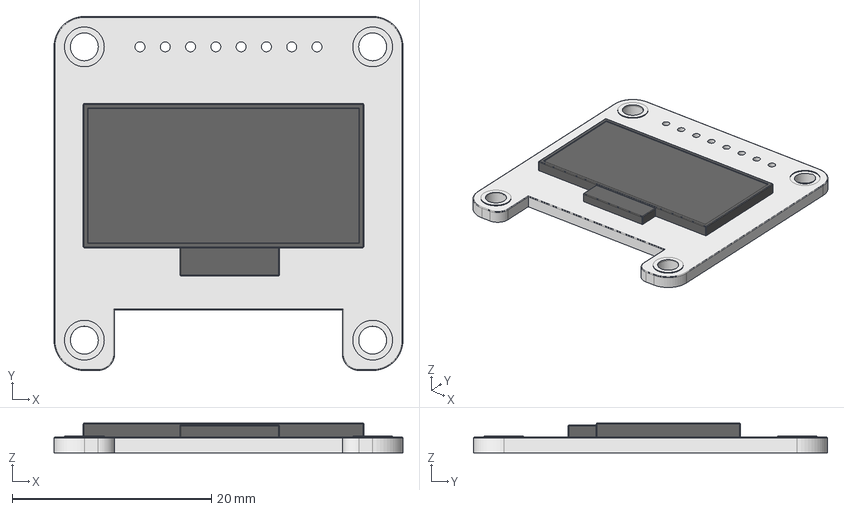
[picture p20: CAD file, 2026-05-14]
Archivos_Kicad/Modelos 3d/Adafruit_SSD1306.FCStd
35.1 x 35.6 x 3.00 mm
Display
Display frame

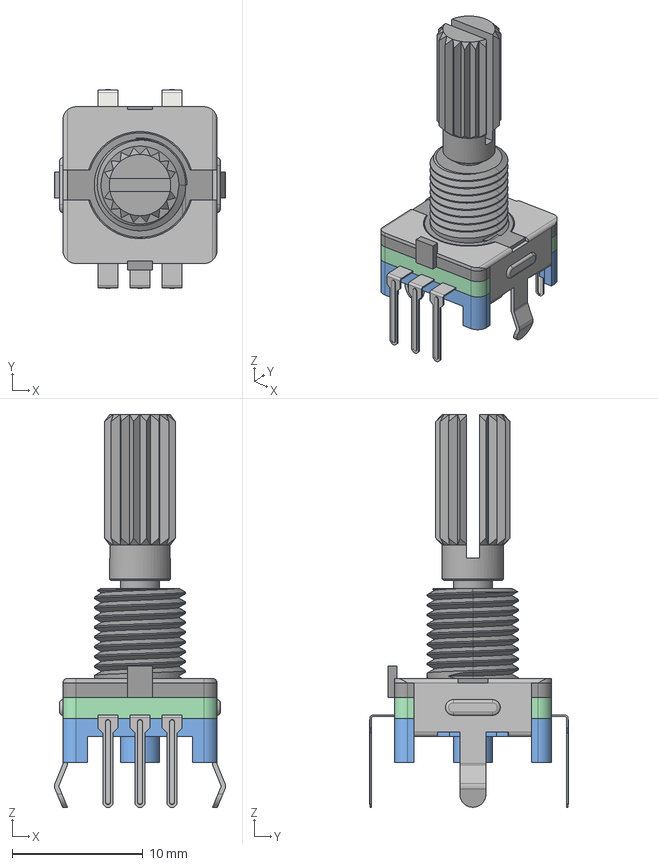
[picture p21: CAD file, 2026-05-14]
Archivos_Kicad/Modelos 3d/EC11_Rotary_Encoder_Switched.step
13.1 x 15.3 x 30.1 mm

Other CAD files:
Archivos_Kicad/Modelos 3d/ESP-12E.scad
Archivos_Kicad/Modelos 3d/REAL_TIME_SHEELD.ipt

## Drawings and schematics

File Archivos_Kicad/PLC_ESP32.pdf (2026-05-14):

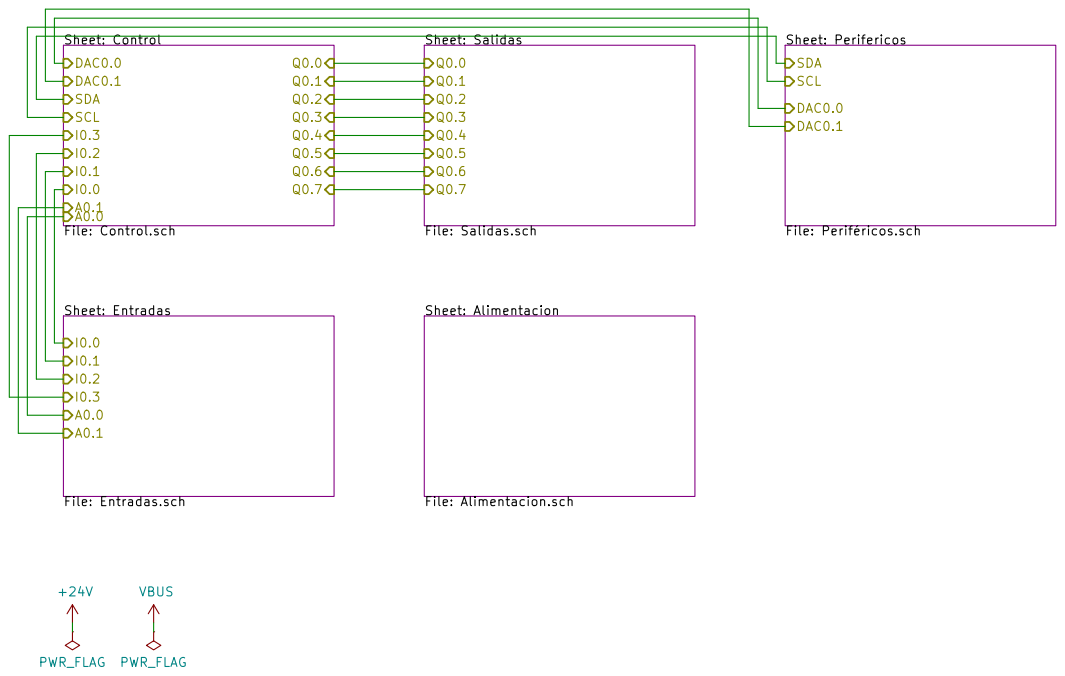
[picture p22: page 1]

I0.2 DAC0.0 DAC0.1 SDA
I0.3 Sheet: Entradas File: Entradas.sch

File: PLC_ESP32.sch Sheet: / Zuliani,Agustin

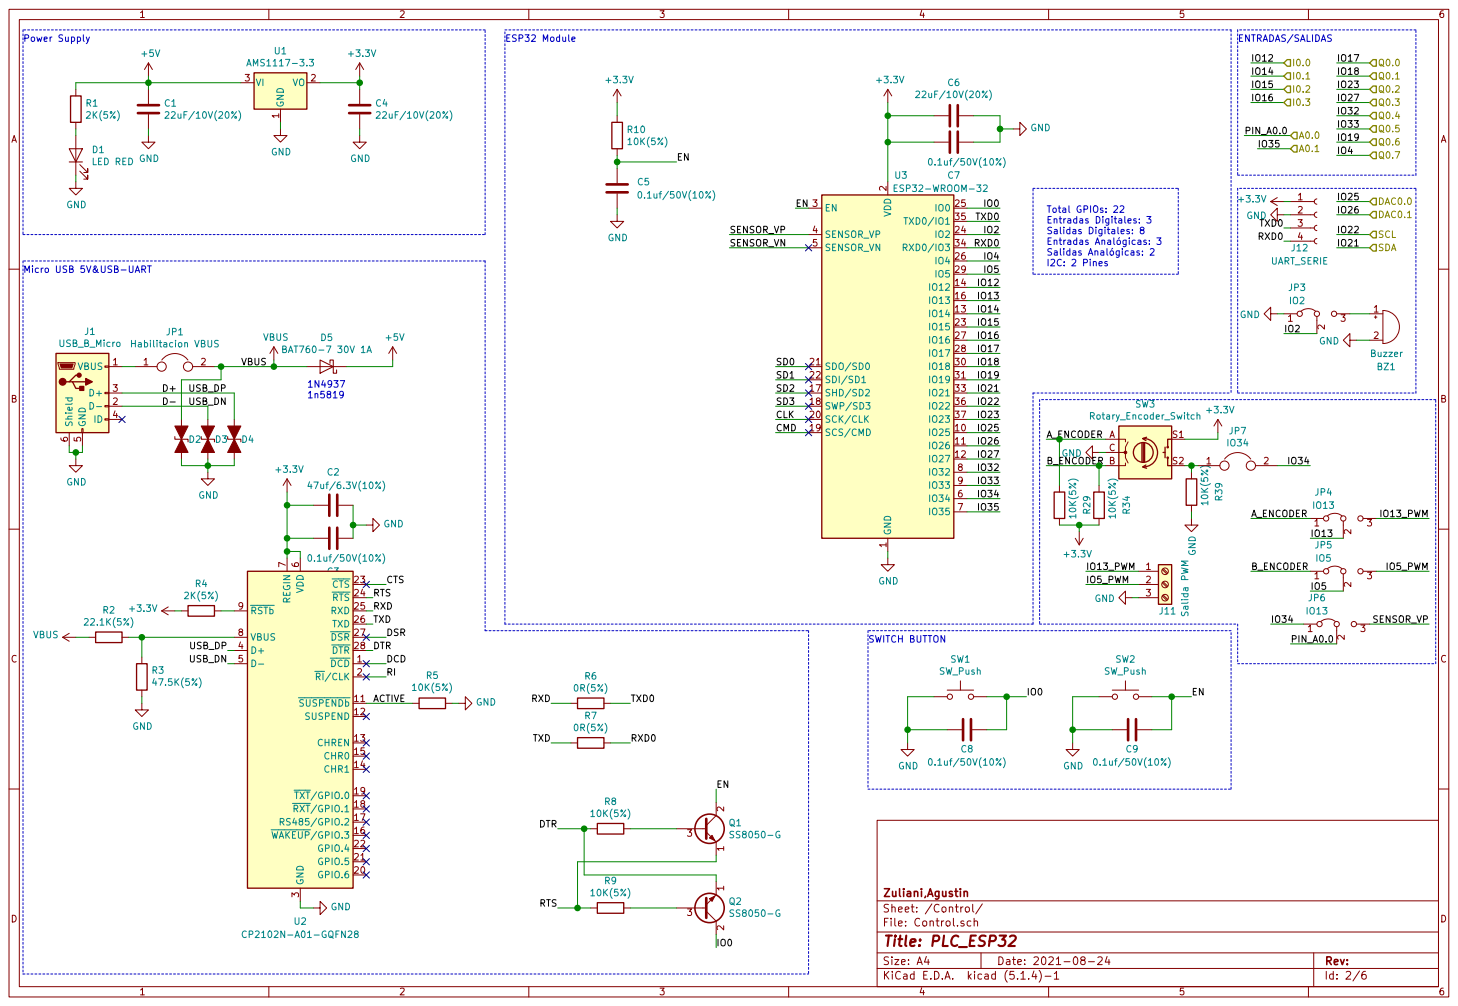
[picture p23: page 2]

2 SCK/CLK 20 SDO/SD0 21 SDI/SD1 22

Total GPIOs: 22 Entradas Digitales: 3

File: Control.sch Sheet: /Control/ Zuliani,Agustin

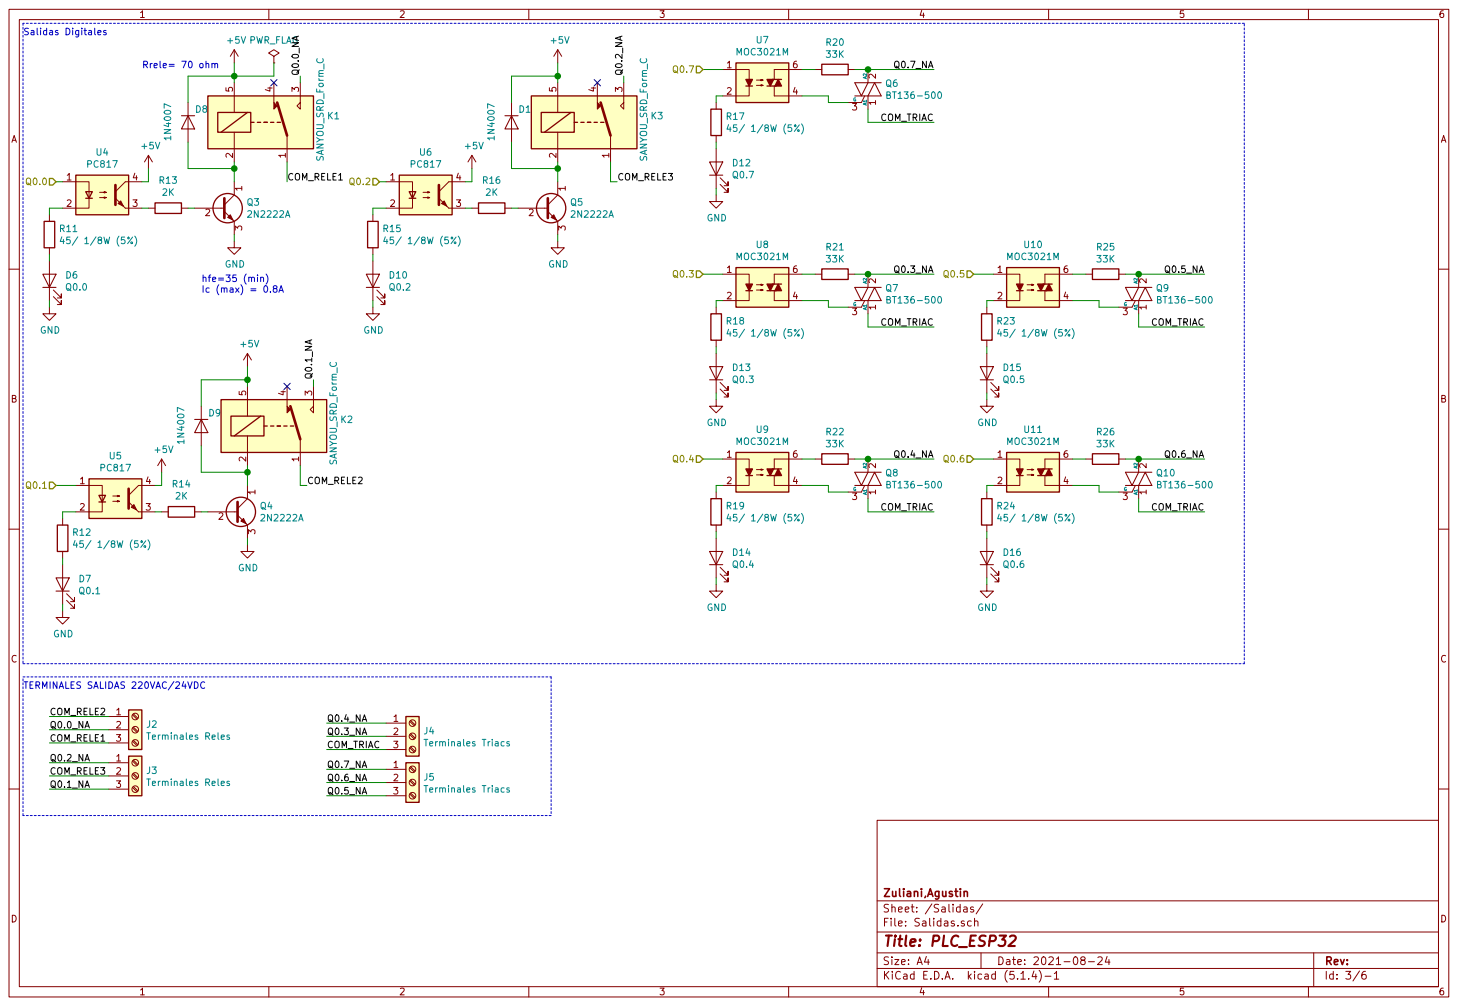
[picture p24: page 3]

Ic (max) = 0.8A Rrele= 70 ohm

File: Salidas.sch Sheet: /Salidas/ Zuliani,Agustin

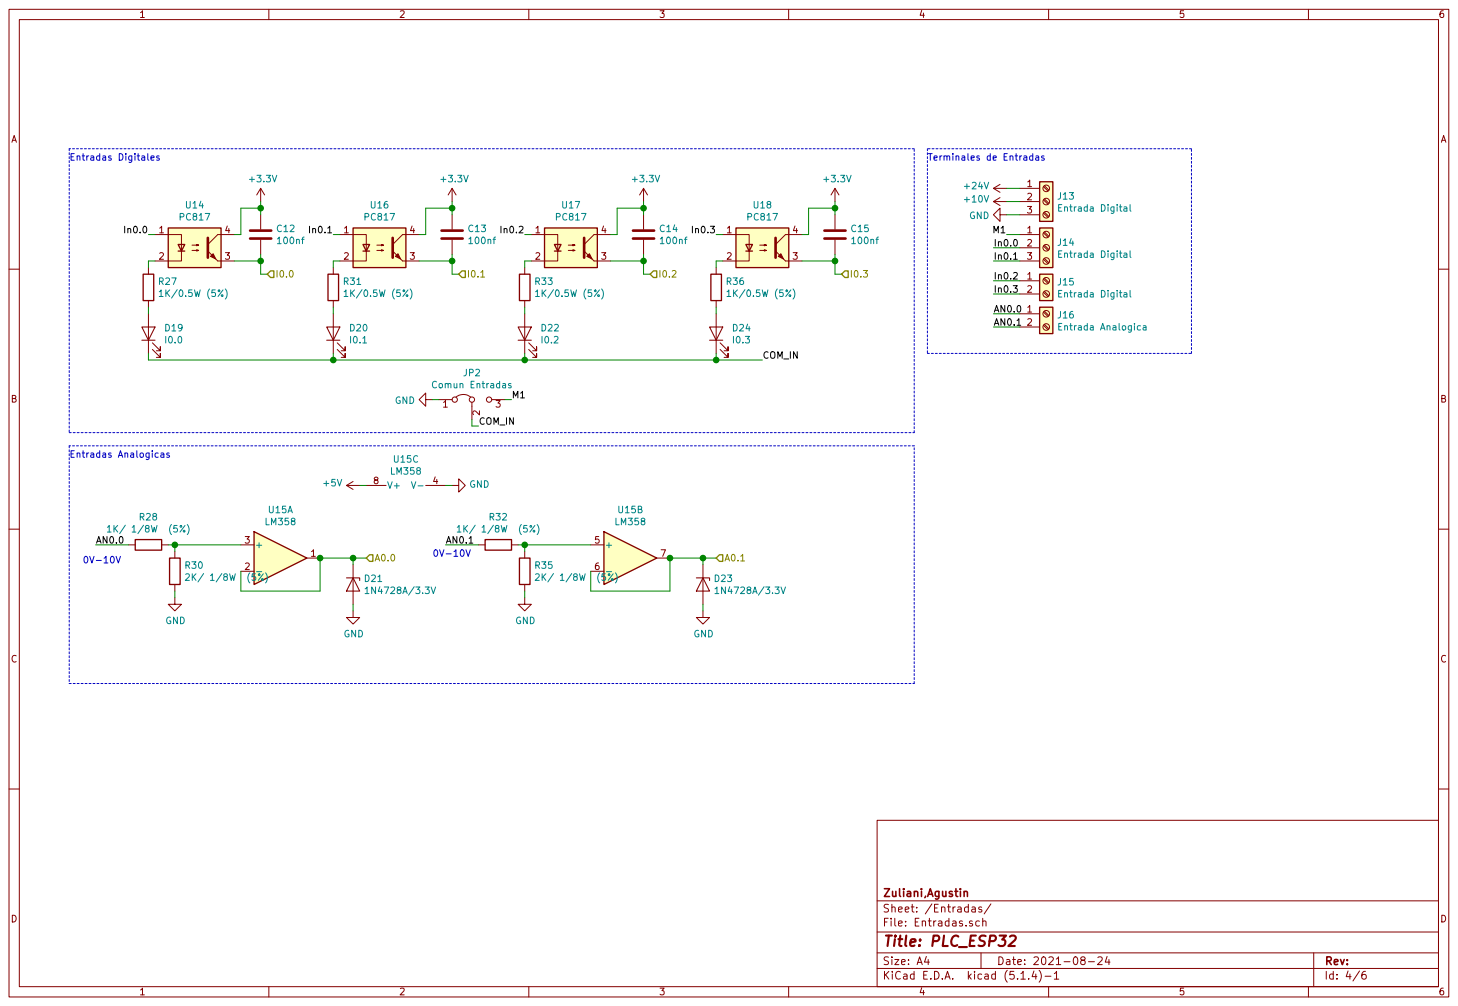
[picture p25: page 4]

File: Entradas.sch Sheet: /Entradas/ Zuliani,Agustin

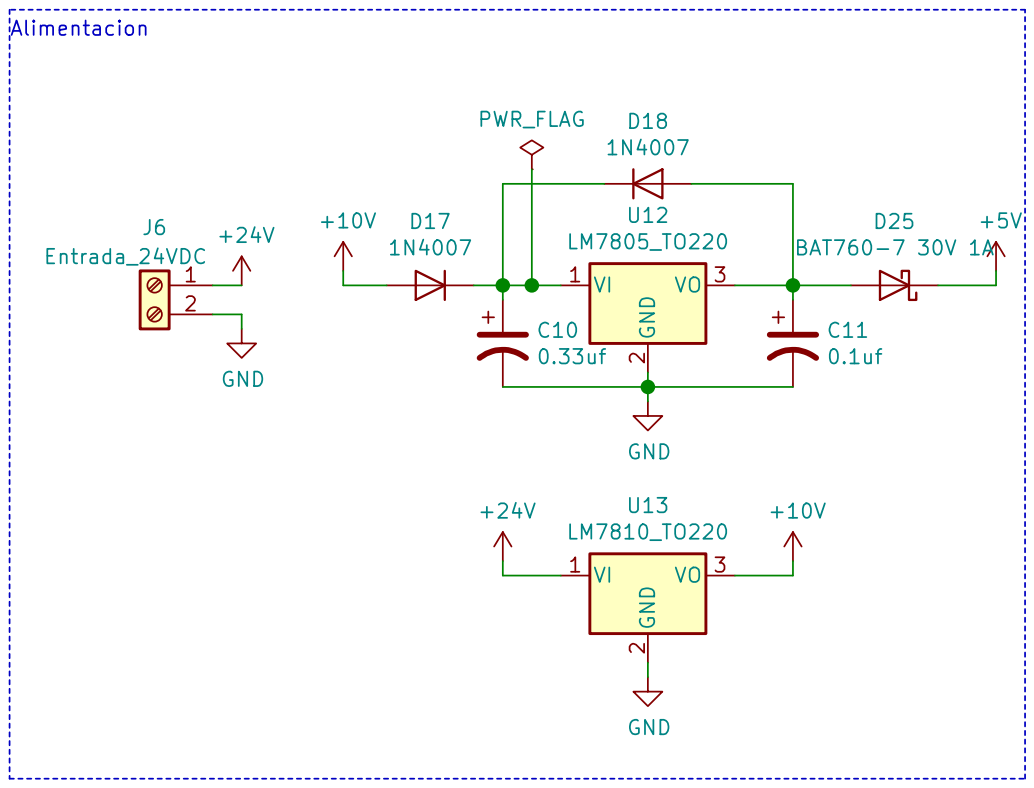
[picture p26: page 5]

File: Alimentacion.sch Sheet: /Alimentacion/ Zuliani,Agustin

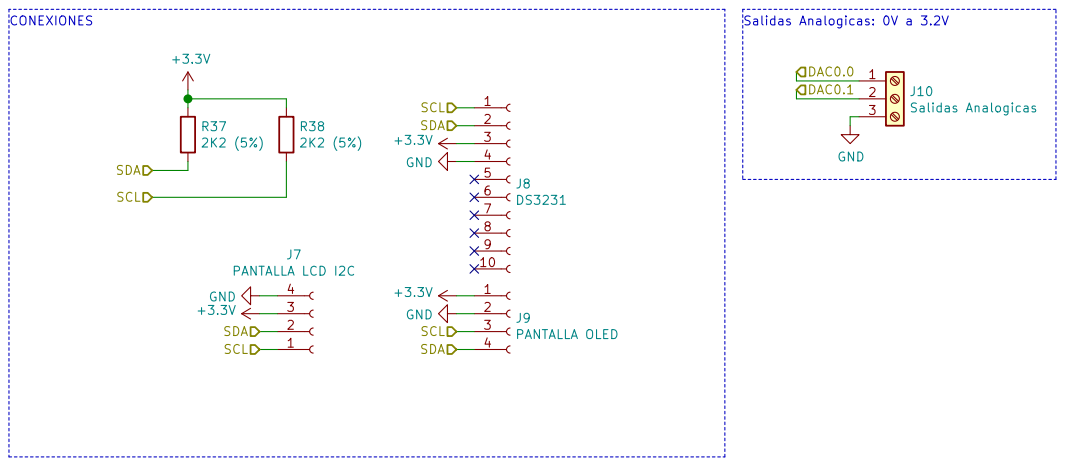
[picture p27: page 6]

File: Periféricos.sch Sheet: /Perifericos/ Zuliani,Agustin

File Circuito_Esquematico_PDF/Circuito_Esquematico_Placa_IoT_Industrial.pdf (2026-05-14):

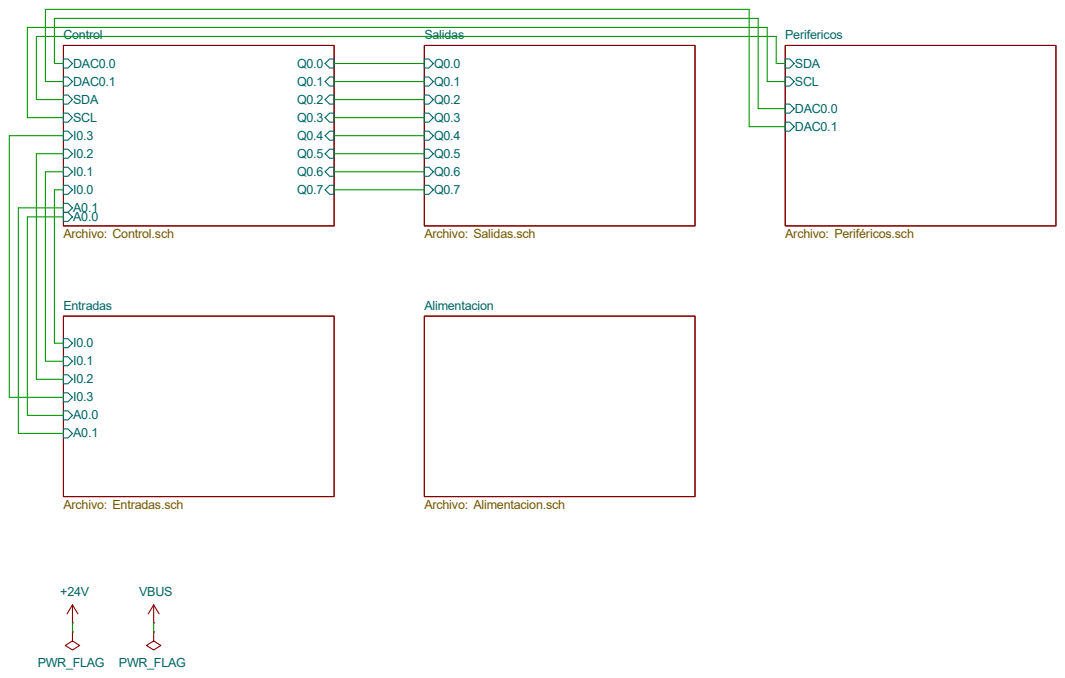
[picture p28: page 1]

SCL DAC0.0 DAC0.1 Perifericos Archivo: Periféricos.sch VBUS

File: PLC_ESP32.sch Sheet: / Zuliani,Agustin

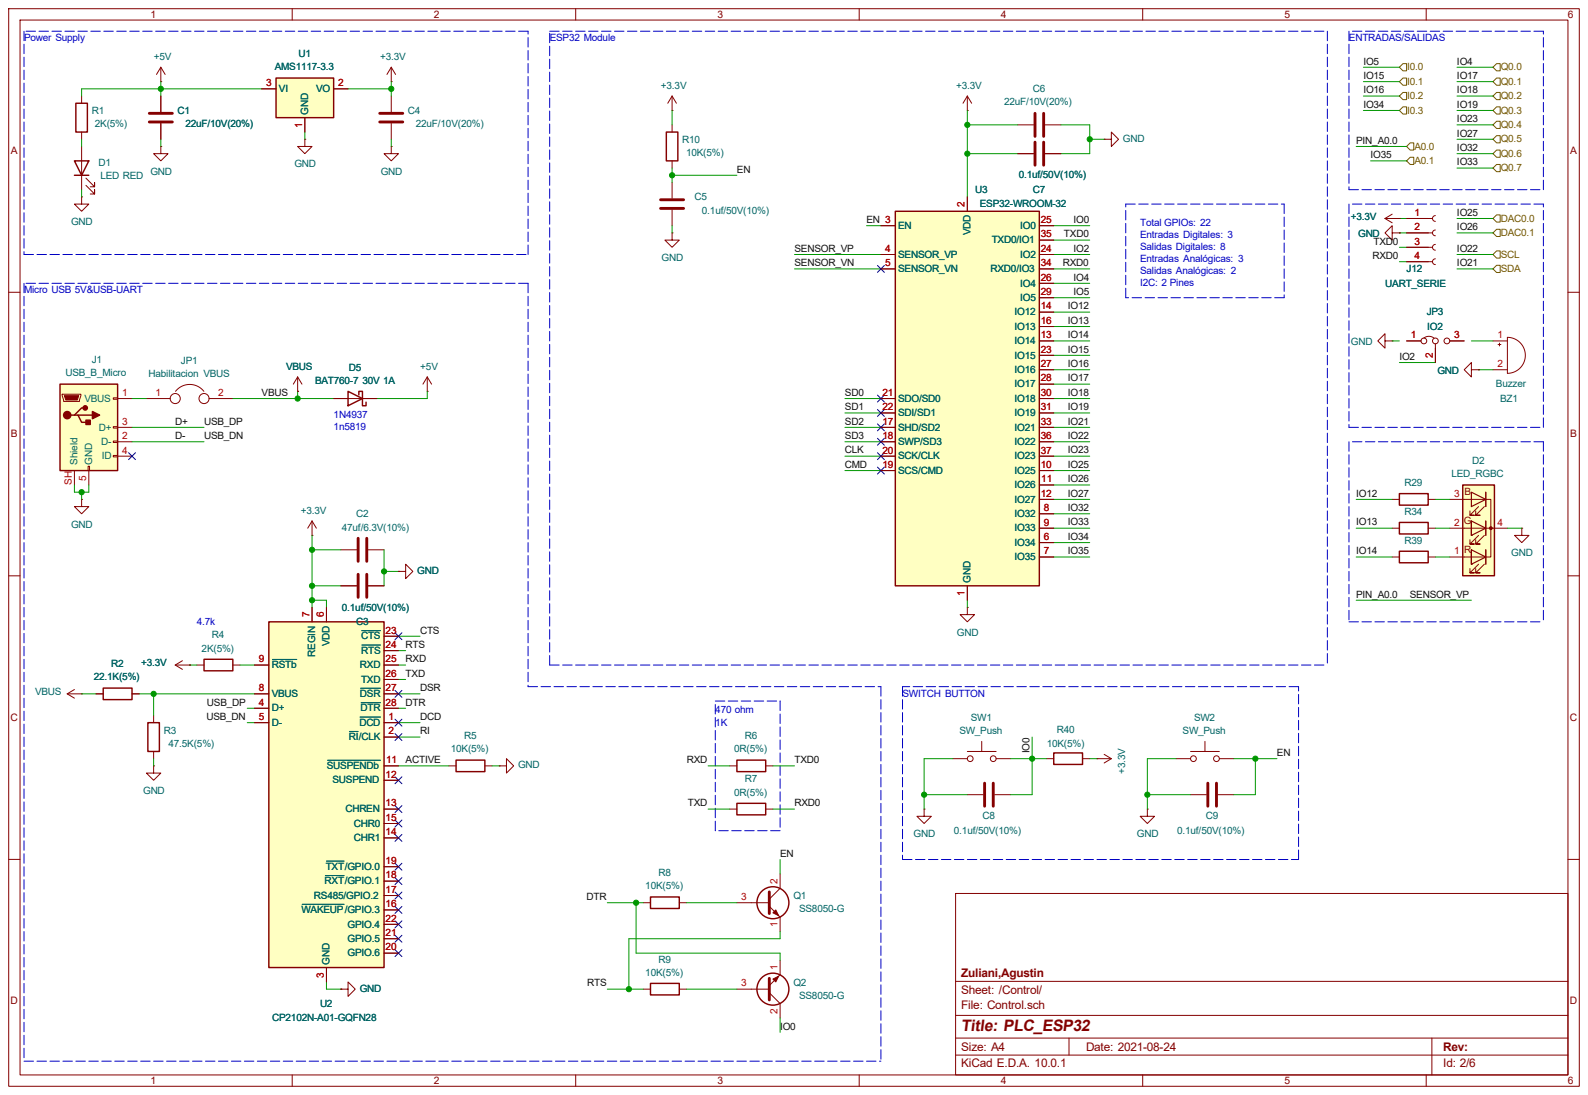
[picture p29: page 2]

Total GPIOs: 22 Entradas Digitales: 3 Salidas Digitales: 8 Entradas Analógicas: 3 Salidas Analógicas: 2

7 VBUS 8 RSTb 9 SUSPENDb 11 SUSPEND 12 CHREN 13 CHR1 14 CHR0 15 WAKEUP/GPIO.3 16 RS485/GPIO.2 17 RXT/GPIO.1 18 TXT/GPIO.0 19 GPIO.6 20 GPIO.5 21 GPIO.4 22 CTS 23 RTS 24 RXD 25 TXD 26 DSR 27 DTR 28 R2 +3.3V

7 VBUS 8 RSTb 9 SUSPENDb 11 SUSPEND 12 CHREN 13 CHR1 14 CHR0 15 WAKEUP/GPIO.3 16 RS485/GPIO.2 17 RXT/GPIO.1 18 TXT/GPIO.0 19 GPIO.6 20 GPIO.5 21 GPIO.4 22 CTS 23 RTS 24 RXD 25 TXD 26 DSR 27 DTR 28 U2 CP2102N-A01-GQFN28 R4

File: Control.sch Sheet: /Control/ Zuliani,Agustin

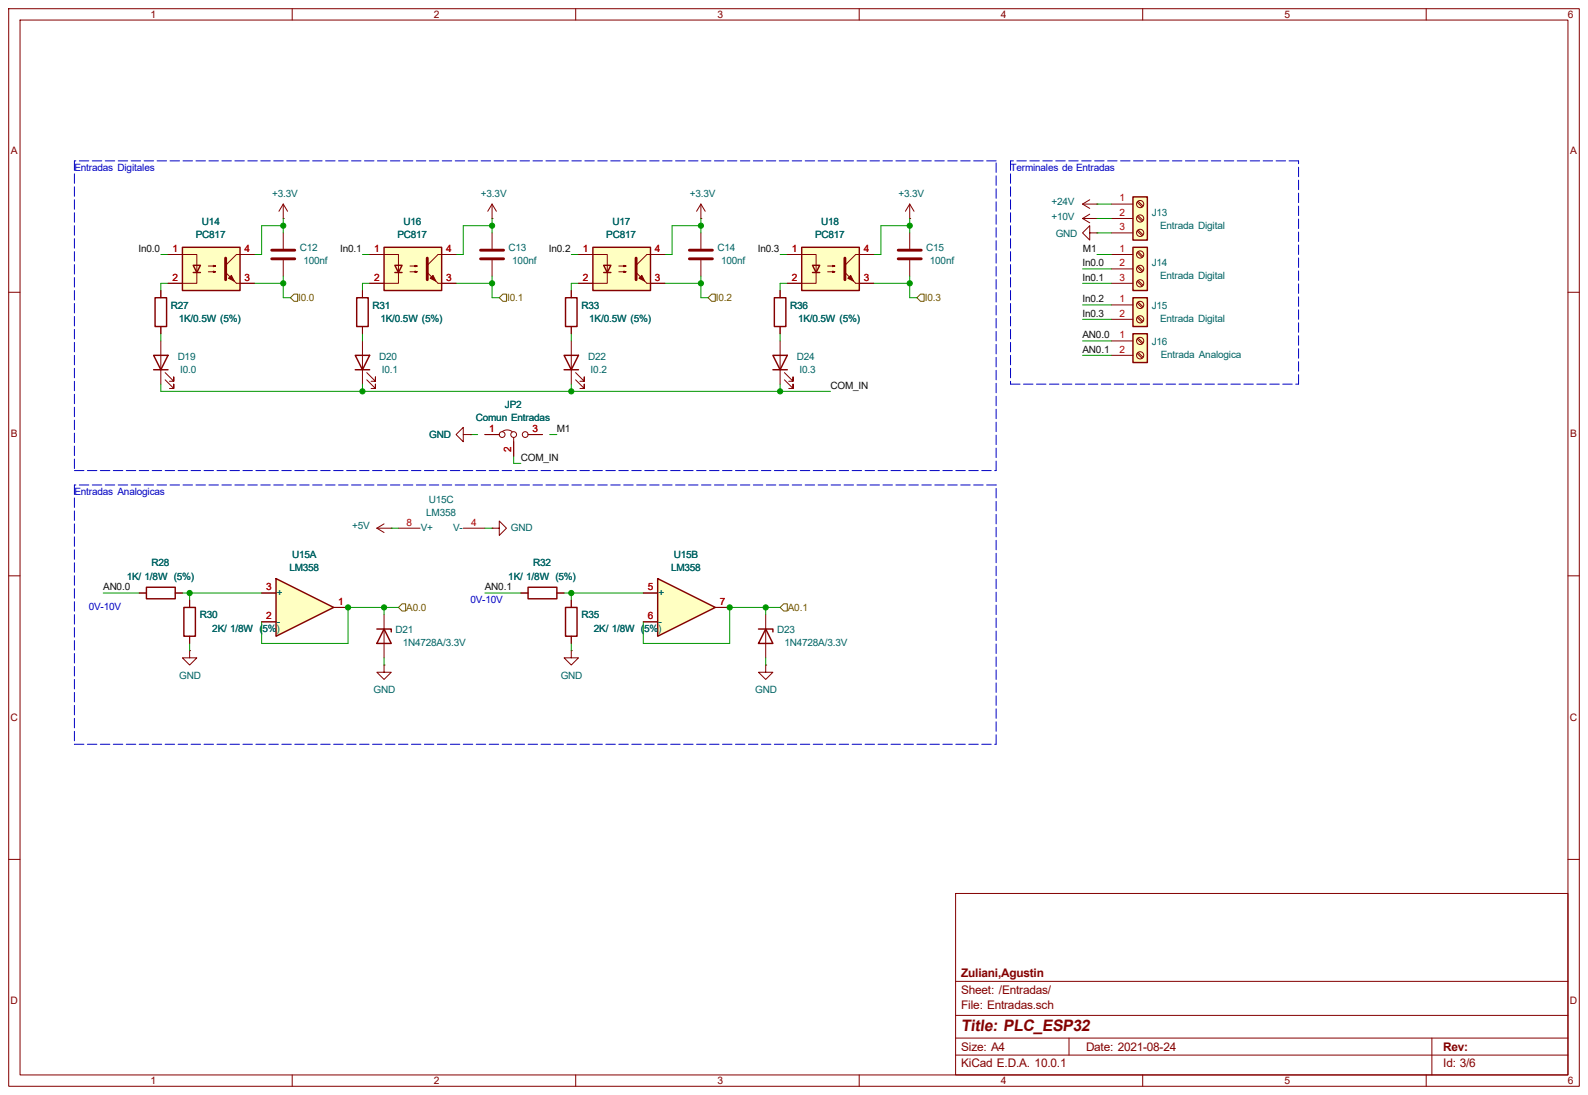
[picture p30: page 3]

File: Entradas.sch Sheet: /Entradas/ Zuliani,Agustin

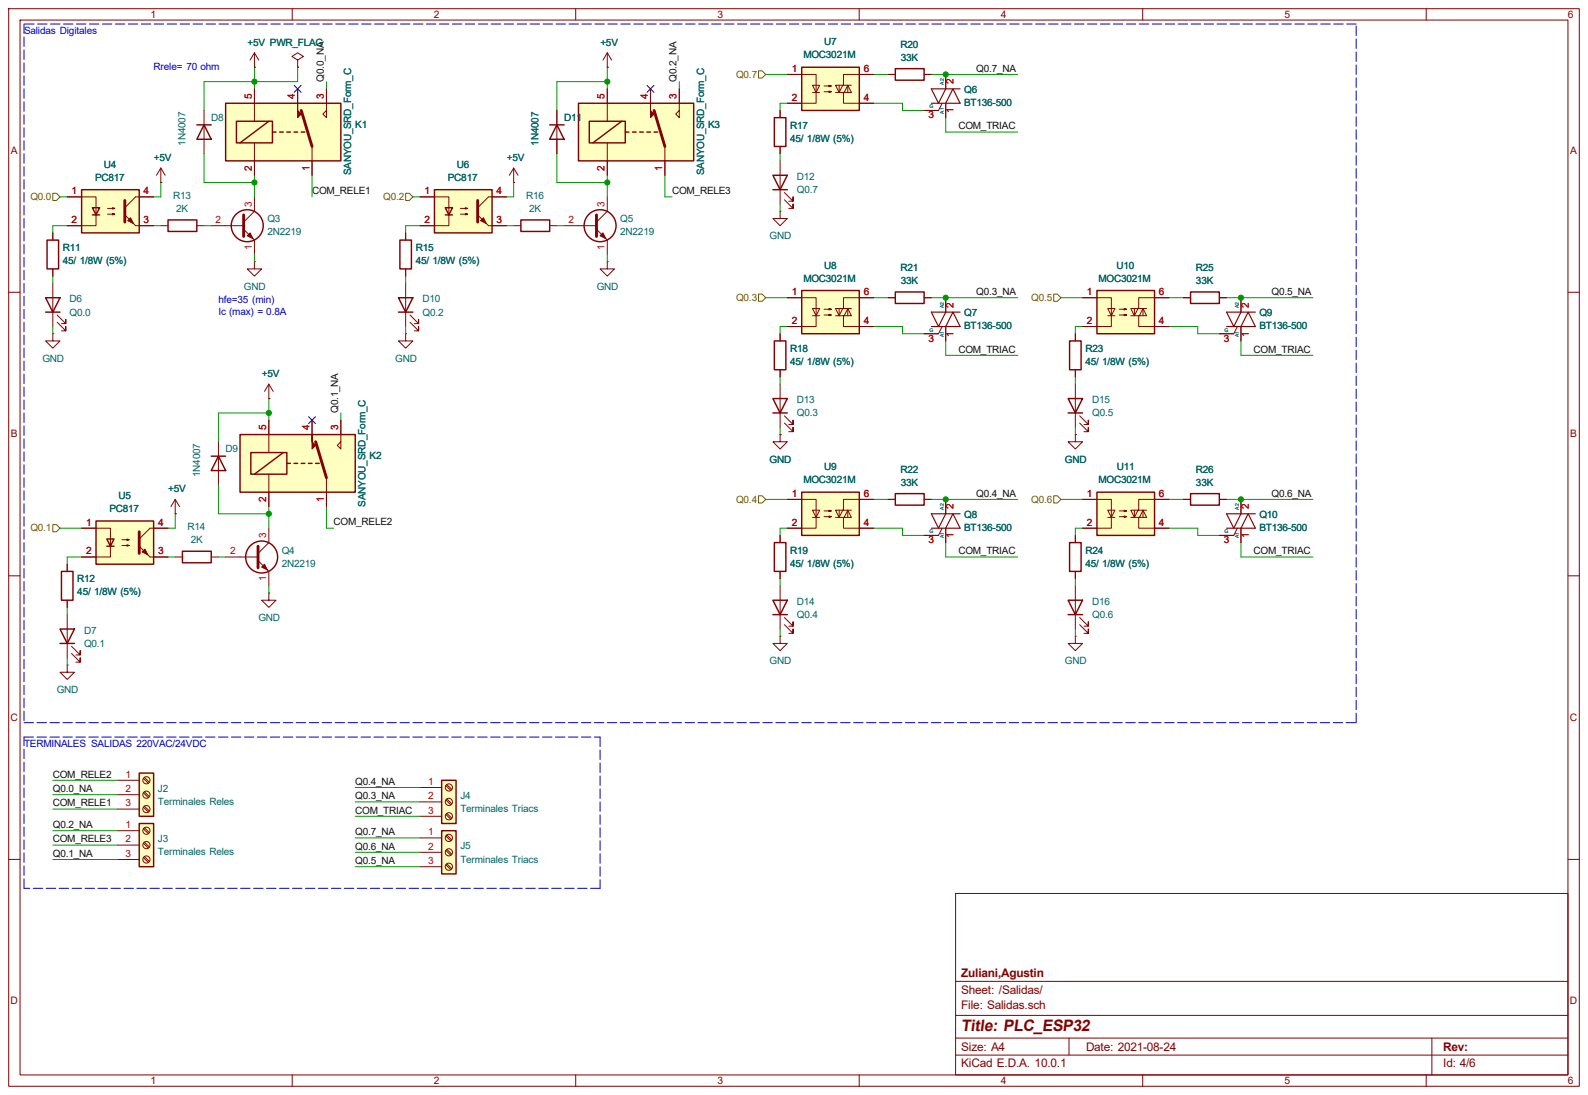
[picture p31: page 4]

File: Salidas.sch Sheet: /Salidas/ Zuliani,Agustin

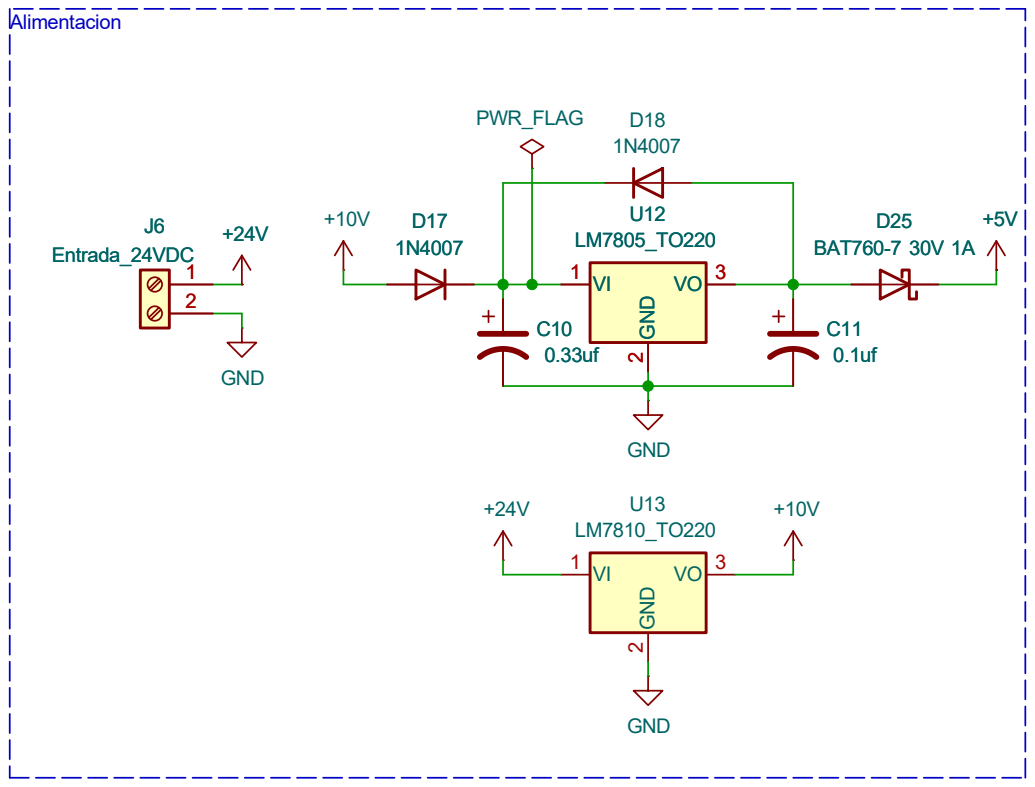
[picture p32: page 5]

File: Alimentacion.sch Sheet: /Alimentacion/ Zuliani,Agustin GND

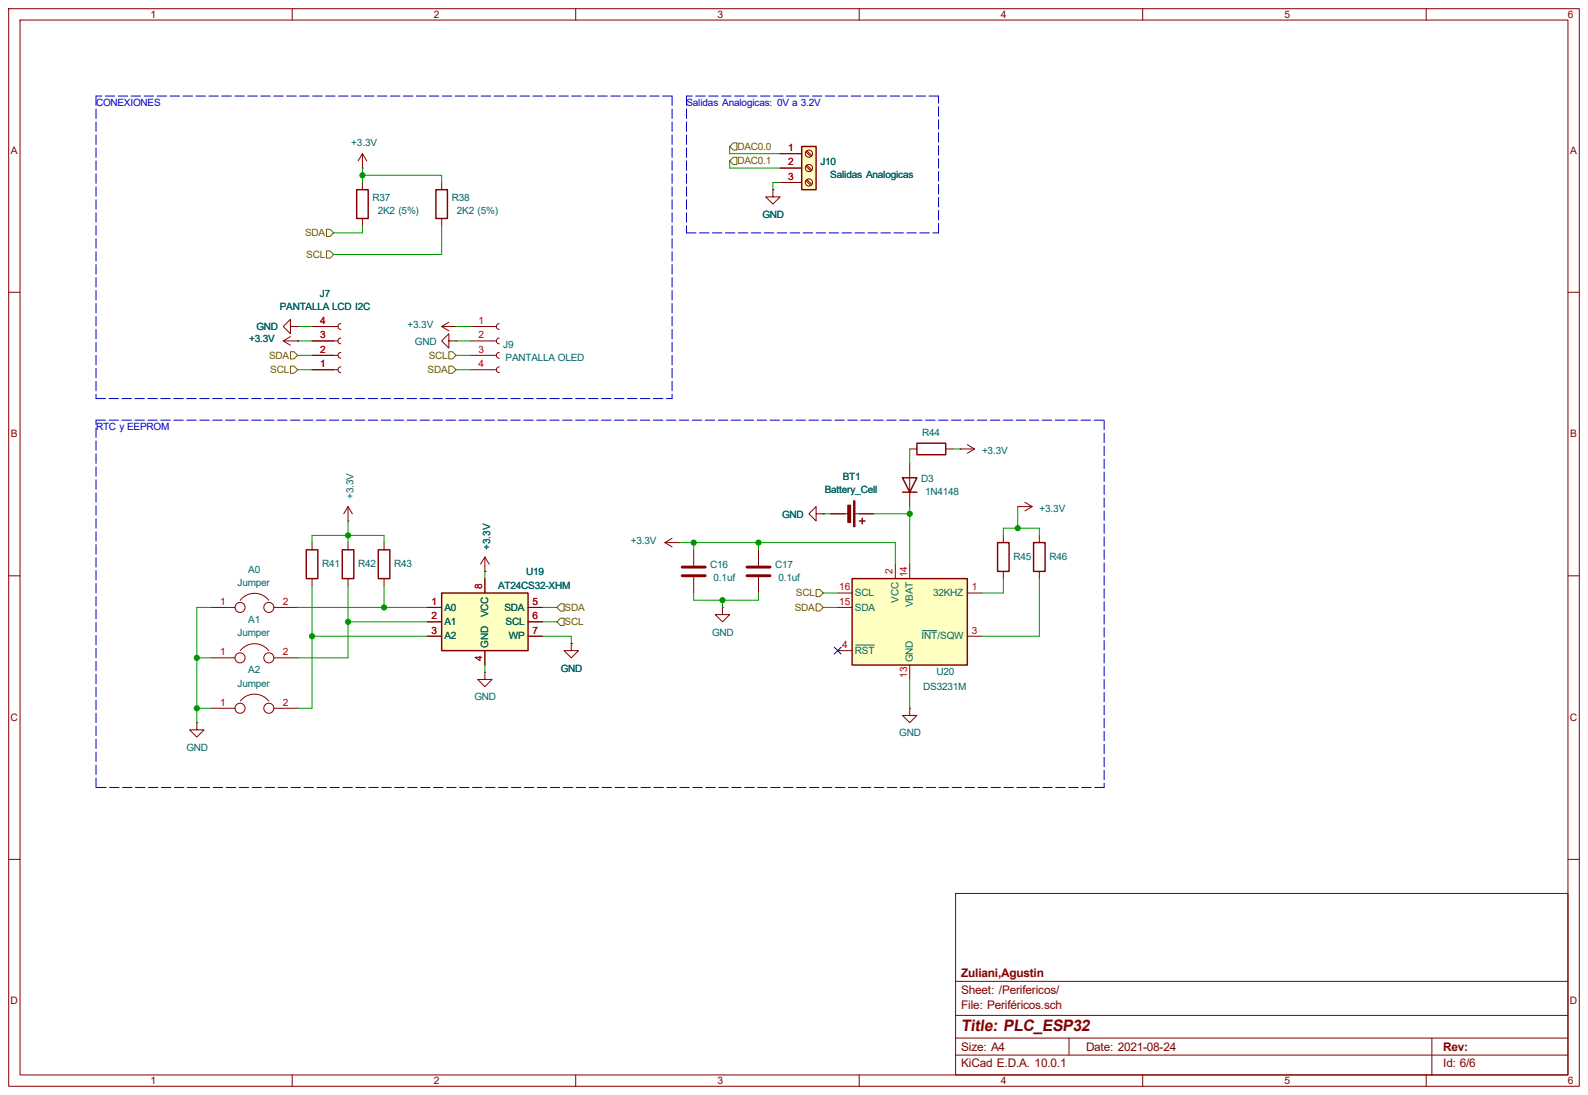
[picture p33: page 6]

4 SDA 5 SCL 6 WP 7 VCC

File: Periféricos.sch Sheet: /Perifericos/ Zuliani,Agustin

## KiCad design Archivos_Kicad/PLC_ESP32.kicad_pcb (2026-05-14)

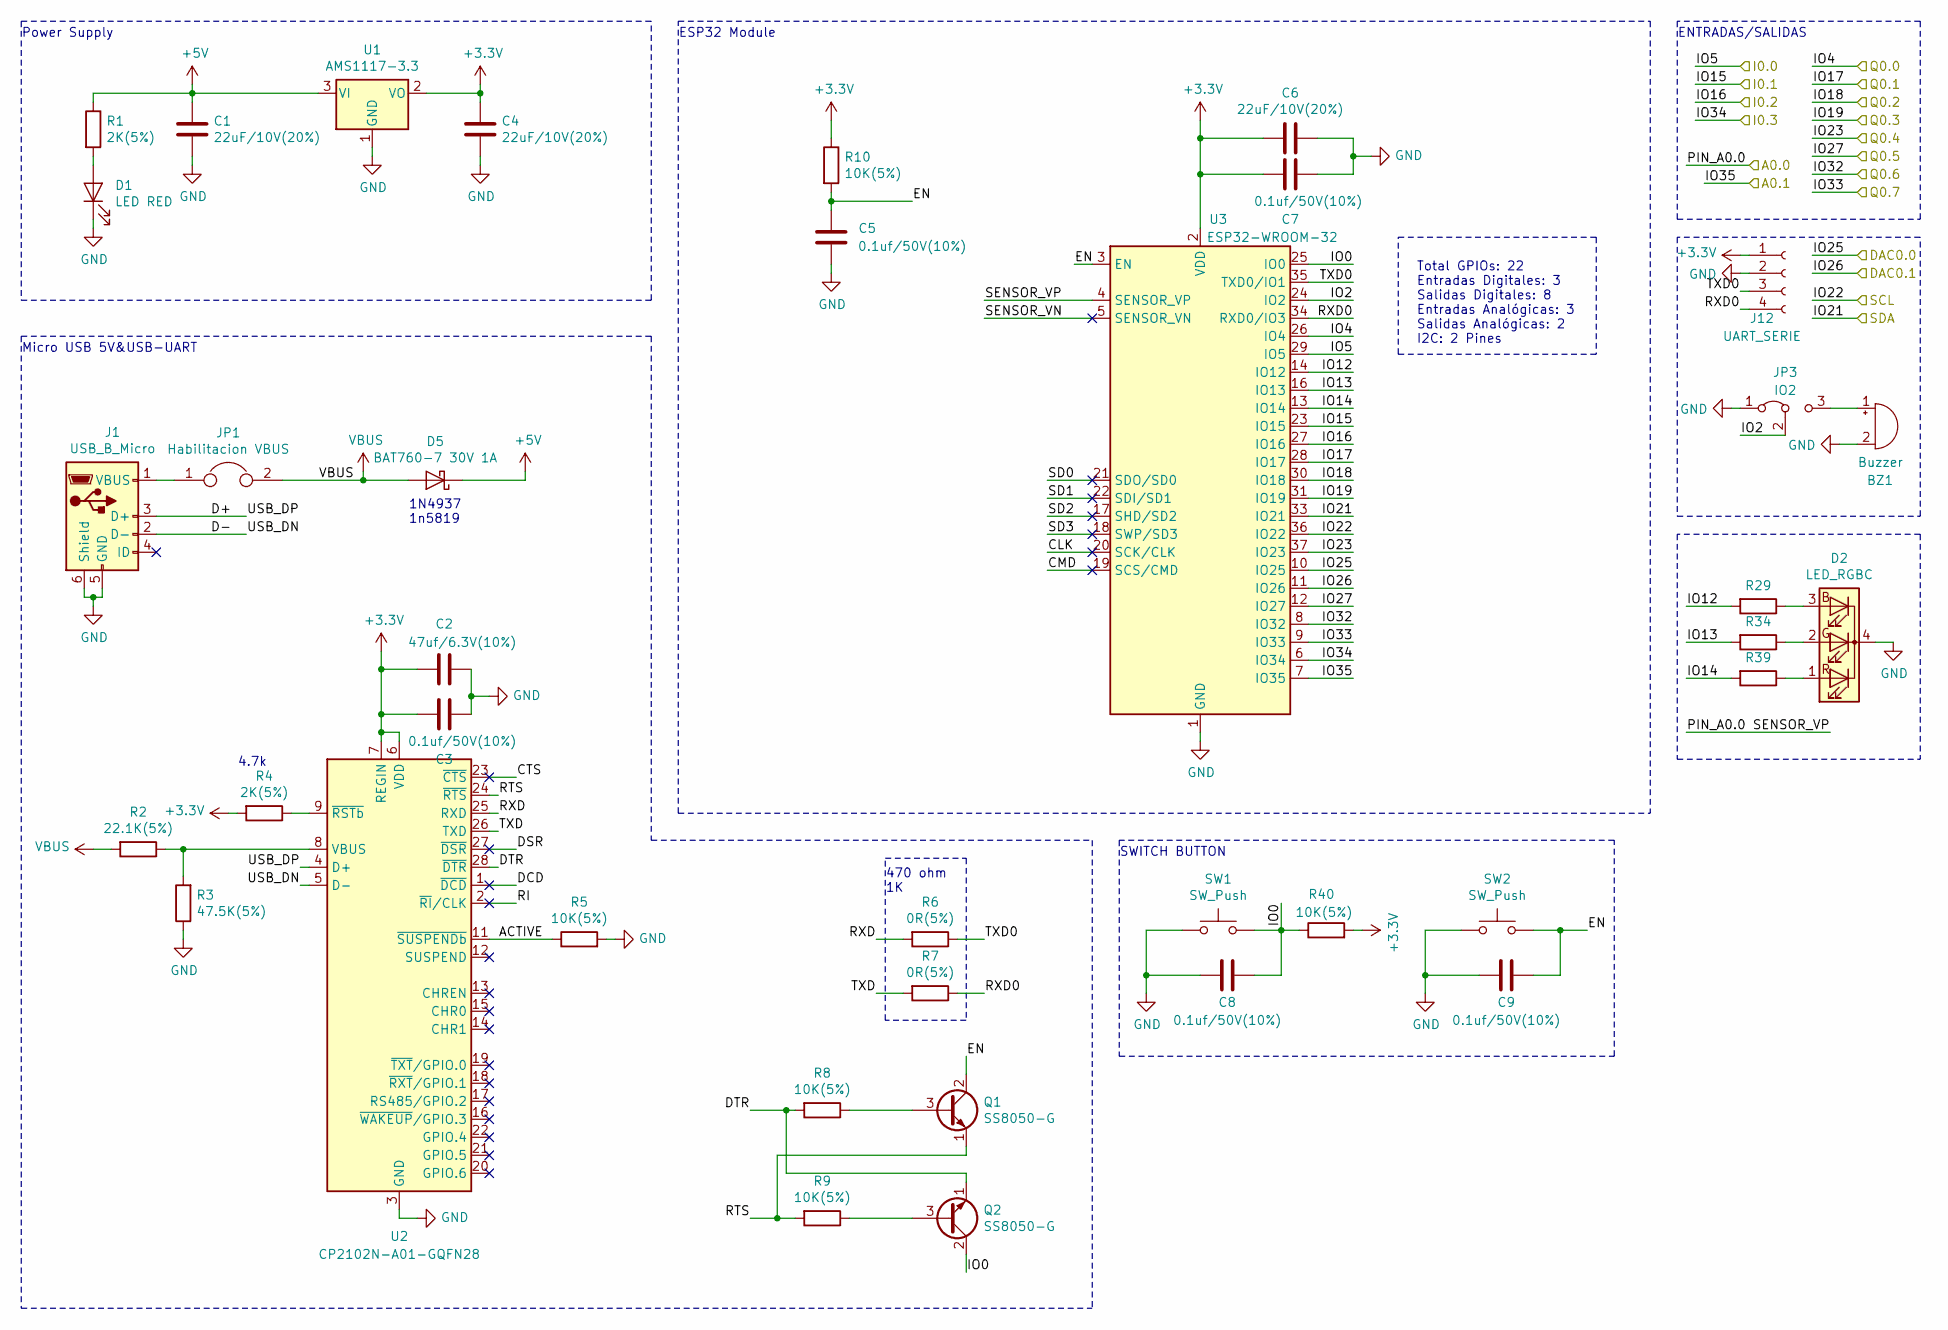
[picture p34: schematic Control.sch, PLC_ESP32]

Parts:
BZ1: Buzzer; Buzzer_12x9.5RM7.6
C1, C4, C6: 22uF/10V(20%); C_0805_2012Metric
C2: 47uf/6.3V(10%); C_0805_2012Metric
C3, C5, C7, C8, C9: 0.1uf/50V(10%); C_0805_2012Metric
D1: LED RED; LED_0805_2012Metric
D2: LED_RGBC; LED_D5.0mm-4_RGB
D5: BAT760-7 30V 1A; D_DO-41_SOD81_P10.16mm_Horizontal
J1: USB_B_Micro; Conn_USBmicro-B_ebay-side_TH
J12: UART_SERIE; PinSocket_1x04_P2.54mm_Horizontal
JP1: Habilitacion VBUS; PinHeader_1x02_P2.54mm_Vertical
JP3: IO2; PinHeader_1x03_P2.54mm_Vertical
Q1, Q2: SS8050-G; SOT-23
R1, R4: 2K(5%); R_0805_2012Metric
R2: 22.1K(5%); R_0805_2012Metric
R3: 47.5K(5%); R_0805_2012Metric
R5, R8, R9, R10, R40: 10K(5%); R_0805_2012Metric
R6, R7: 0R(5%); R_0805_2012Metric
R29, R34, R39: 100 Ohm 1/8W 5%; R_0805_2012Metric
SW1, SW2: SW_Push; SW_PUSH_6mm
U1: AMS1117-3.3; SOT-223-3_TabPin2
U2: CP2102N-A01-GQFN28; QFN-28-1EP_5x5mm_P0.5mm_EP3.35x3.35mm
U3: ESP32-WROOM-32

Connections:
+3V3: C2.2, C3.2, C4.1, C6.2, C7.2, J12.1, R4.2, R10.1, R40.2, U1.2 (VO), U2.6 (VDD), U2.7 (REGIN), U3.2 (VDD); also elsewhere on the board
+5V: C1.1, D5.1 (K), R1.1, U1.3 (VI); also elsewhere on the board
/Control/A0.0: U3.4 (SENSOR_VP); also elsewhere on the board
/Control/A0.1: U3.7 (IO35); also elsewhere on the board
/Control/ACTIVE: R5.1, U2.11 (~SUSPENDb)
/Control/CLK: U3.20 (SCK/CLK)
/Control/CMD: U3.19 (SCS/CMD)
/Control/CTS: U2.23 (~CTS)
/Control/D+: J1.3 (D+), U2.4 (D+)
/Control/D-: J1.2 (D-), U2.5 (D-)
/Control/DAC0.0: U3.10 (IO25); also elsewhere on the board
/Control/DAC0.1: U3.11 (IO26); also elsewhere on the board
/Control/DCD: U2.1 (~DCD)
/Control/DSR: U2.27 (~DSR)
/Control/DTR: Q2.1 (E), R8.2, U2.28 (~DTR)
/Control/EN: C5.1, C9.1, Q1.2 (C), R10.2, SW2.2, U3.3 (EN)
/Control/I0.0: U3.29 (IO5); also elsewhere on the board
/Control/I0.1: U3.23 (IO15); also elsewhere on the board
/Control/I0.2: U3.27 (IO16); also elsewhere on the board
/Control/I0.3: U3.6 (IO34); also elsewhere on the board
/Control/IO0: C8.1, Q2.2 (C), R40.1, SW1.2, U3.25 (IO0)
/Control/IO2: JP3.2 (C), U3.24 (IO2)
/Control/IO12: R29.2, U3.14 (IO12)
/Control/IO13: R34.2, U3.16 (IO13)
/Control/IO14: R39.2, U3.13 (IO14)
/Control/Q0.0: U3.26 (IO4); also elsewhere on the board
/Control/Q0.1: U3.28 (IO17); also elsewhere on the board
/Control/Q0.2: U3.30 (IO18); also elsewhere on the board
/Control/Q0.3: U3.31 (IO19); also elsewhere on the board
/Control/Q0.4: U3.37 (IO23); also elsewhere on the board
/Control/Q0.5: U3.12 (IO27); also elsewhere on the board
/Control/Q0.6: U3.8 (IO32); also elsewhere on the board
/Control/Q0.7: U3.9 (IO33); also elsewhere on the board
/Control/RI: U2.2 (~RI~/CLK)
/Control/RTS: Q1.1 (E), R9.2, U2.24 (~RTS)
/Control/RXD: R6.2, U2.25 (RXD)
/Control/RXD0: J12.4, R7.1, U3.34 (RXD0/IO3)
/Control/SCL: U3.36 (IO22); also elsewhere on the board
/Control/SD0: U3.21 (SDO/SD0)
/Control/SD1: U3.22 (SDI/SD1)
/Control/SD2: U3.17 (SHD/SD2)
/Control/SD3: U3.18 (SWP/SD3)
/Control/SDA: U3.33 (IO21); also elsewhere on the board
/Control/SENSOR_VN: U3.5 (SENSOR_VN)
/Control/TXD: R7.2, U2.26 (TXD)
/Control/TXD0: J12.3, R6.1, U3.35 (TXD0/IO1)
GND: BZ1.2 (+), C1.2, C2.1, C3.1, C4.2, C5.2, C6.1, C7.1, C8.2, C9.2, D1.1 (K), D2.4 (K), J1.5 (GND), J1.6 (Shield), J12.2, JP3.1 (A), R3.1, R5.2, SW1.1, SW2.1, U1.1 (GND), U2.3 (GND), U2.29 (GND), U3.1 (GND), U3.15 (GND), U3.38 (GND); also elsewhere on the board
unnamed: BZ1.1 (-), JP3.3 (B)
unnamed: D1.2 (A), R1.2
unnamed: D2.1 (RA), R39.1
unnamed: D2.2 (GA), R34.1
unnamed: D2.3 (BA), R29.1
unnamed: J1.1 (VBUS), JP1.1
unnamed: Q1.3 (B), R8.1
unnamed: Q2.3 (B), R9.1
unnamed: R2.1, R3.2, U2.8 (VBUS)
unnamed: R4.1, U2.9 (~RSTb)
VBUS: D5.2 (A), JP1.2, R2.2

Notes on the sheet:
Power Supply
Micro USB 5V&USB-UART
ESP32 Module
SWITCH BUTTON
Total GPIOs: 22 Entradas Digitales: 3 Salidas Digitales: 8 Entradas Analógicas: 3 Salidas Analógicas: 2 I2C: 2 Pines
ENTRADAS/SALIDAS
1N4937 1n5819
470 ohm 1K
4.7k

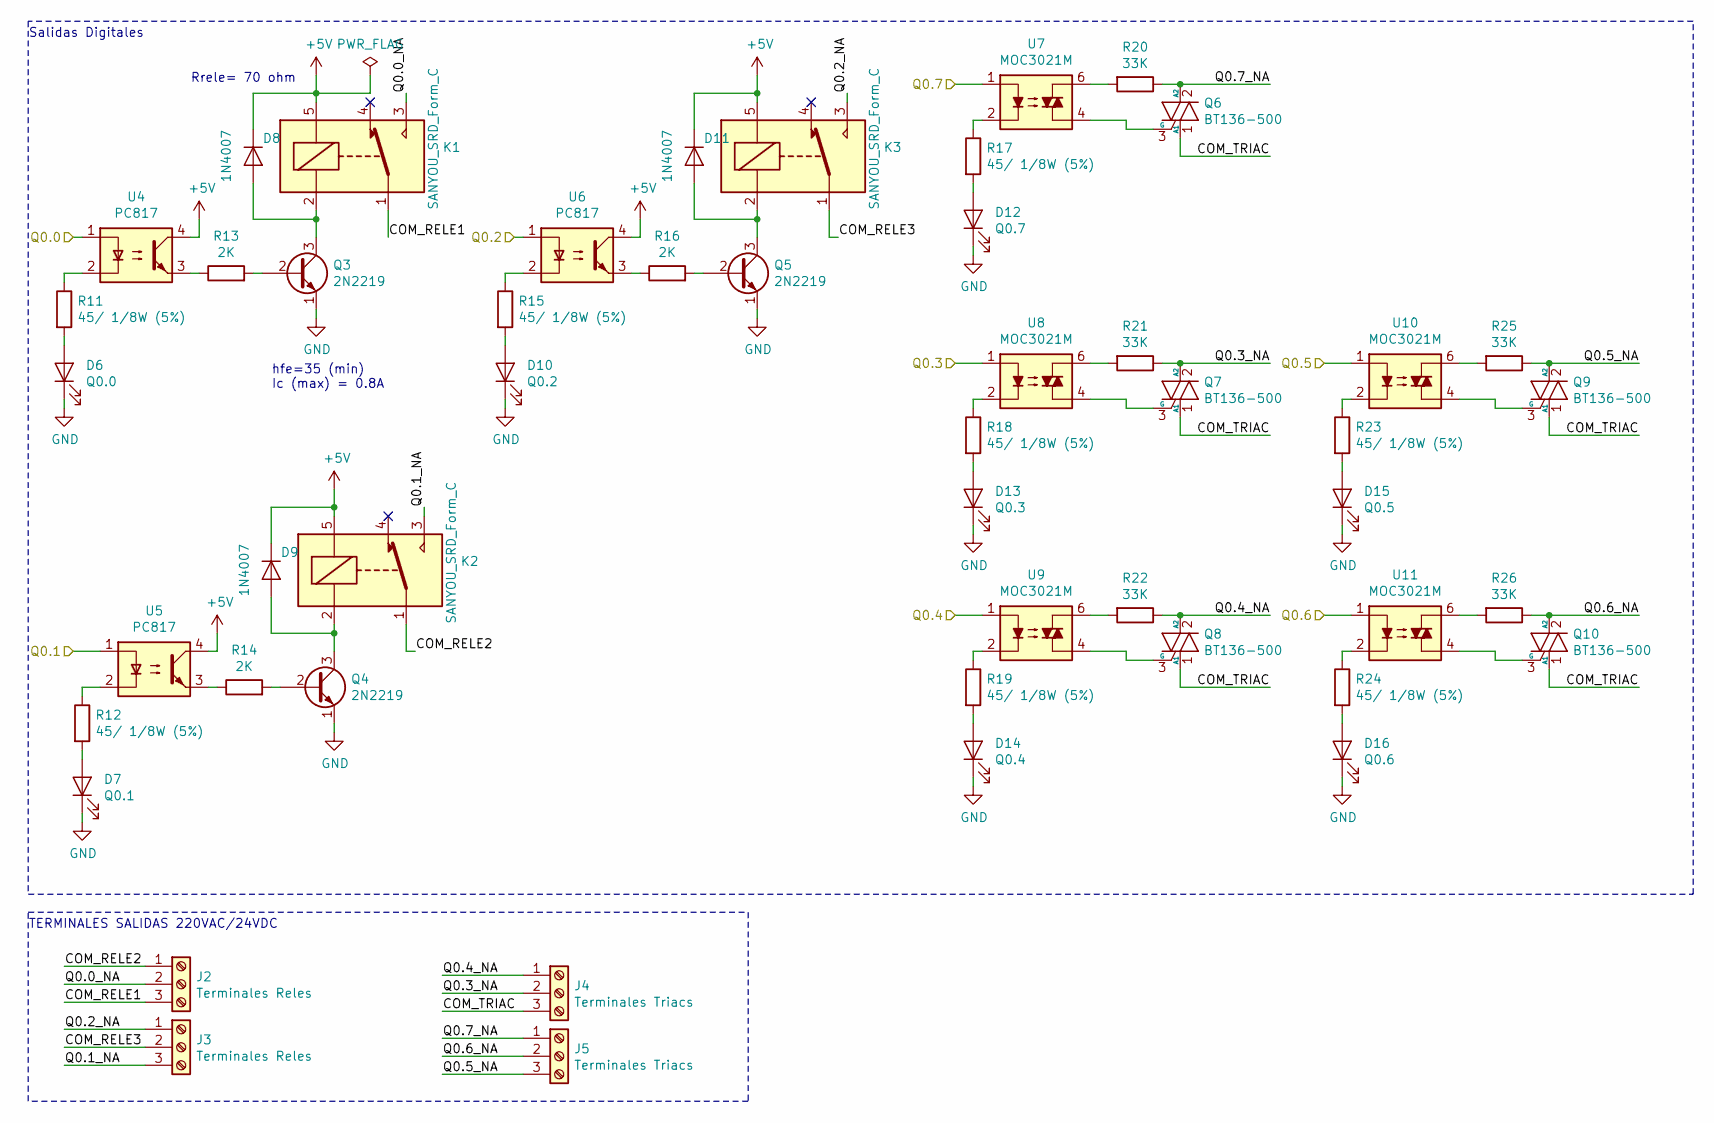
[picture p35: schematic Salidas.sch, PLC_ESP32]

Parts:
D6: Q0.0; LED_0805_2012Metric
D7: Q0.1; LED_0805_2012Metric
D8, D9, D11: 1N4007; D_SMA
D10: Q0.2; LED_0805_2012Metric
D12: Q0.7; LED_0805_2012Metric
D13: Q0.3; LED_0805_2012Metric
D14: Q0.4; LED_0805_2012Metric
D15: Q0.5; LED_0805_2012Metric
D16: Q0.6; LED_0805_2012Metric
J2, J3: Terminales Reles; TerminalBlock_Phoenix_PT-1,5-3-5.0-H_1x03_P5.00mm_Horizontal
J4, J5: Terminales Triacs; TerminalBlock_Phoenix_PT-1,5-3-5.0-H_1x03_P5.00mm_Horizontal
K1, K2, K3: SANYOU_SRD_Form_C; Relay_SPDT_SANYOU_SRD_Series_Form_C
Q3, Q4, Q5: 2N2219; TO-92_Inline
Q6, Q7, Q8, Q9, Q10: BT136-500; TO-220-3_Vertical
R11, R12, R15, R17, R18, R19, R23, R24: 45/ 1/8W (5%); R_0805_2012Metric
R13, R14, R16: 2K; R_0805_2012Metric
R20, R21, R22, R25, R26: 33K; R_Axial_DIN0207_L6.3mm_D2.5mm_P10.16mm_Horizontal
U4, U5, U6: PC817; DIP-4_W7.62mm_LongPads
U7, U8, U9, U10, U11: MOC3021M; DIP-6_W7.62mm_LongPads

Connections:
+5V: D8.1 (K), D9.1 (K), D11.1 (K), K1.5, K2.5, K3.5, U4.4, U5.4, U6.4; also elsewhere on the board
/Control/Q0.0: U4.1; also elsewhere on the board
/Control/Q0.1: U5.1; also elsewhere on the board
/Control/Q0.2: U6.1; also elsewhere on the board
/Control/Q0.3: U8.1; also elsewhere on the board
/Control/Q0.4: U9.1; also elsewhere on the board
/Control/Q0.5: U10.1; also elsewhere on the board
/Control/Q0.6: U11.1; also elsewhere on the board
/Control/Q0.7: U7.1; also elsewhere on the board
/Salidas/COM_RELE1: J2.3, K1.1
/Salidas/COM_RELE2: J2.1, K2.1
/Salidas/COM_RELE3: J3.2, K3.1
/Salidas/COM_TRIAC: J4.3, Q6.1 (A1), Q7.1 (A1), Q8.1 (A1), Q9.1 (A1), Q10.1 (A1)
/Salidas/Q0.0_NA: J2.2, K1.3
/Salidas/Q0.1_NA: J3.3, K2.3
/Salidas/Q0.2_NA: J3.1, K3.3
/Salidas/Q0.3_NA: J4.2, Q7.2 (A2), R21.1
/Salidas/Q0.4_NA: J4.1, Q8.2 (A2), R22.1
/Salidas/Q0.5_NA: J5.3, Q9.2 (A2), R25.1
/Salidas/Q0.6_NA: J5.2, Q10.2 (A2), R26.1
/Salidas/Q0.7_NA: J5.1, Q6.2 (A2), R20.1
GND: D6.1 (K), D7.1 (K), D10.1 (K), D12.1 (K), D13.1 (K), D14.1 (K), D15.1 (K), D16.1 (K), Q3.1 (E), Q4.1 (E), Q5.1 (E); also elsewhere on the board
unnamed: D6.2 (A), R11.2
unnamed: D7.2 (A), R12.2
unnamed: D8.2 (A), K1.2, Q3.3 (C)
unnamed: D9.2 (A), K2.2, Q4.3 (C)
unnamed: D10.2 (A), R15.2
unnamed: D11.2 (A), K3.2, Q5.3 (C)
unnamed: D12.2 (A), R17.2
unnamed: D13.2 (A), R18.2
unnamed: D14.2 (A), R19.2
unnamed: D15.2 (A), R23.2
unnamed: D16.2 (A), R24.2
unnamed: Q3.2 (B), R13.2
unnamed: Q4.2 (B), R14.2
unnamed: Q5.2 (B), R16.2
unnamed: Q6.3 (G), U7.4
unnamed: Q7.3 (G), U8.4
unnamed: Q8.3 (G), U9.4
unnamed: Q9.3 (G), U10.4
unnamed: Q10.3 (G), U11.4
unnamed: R11.1, U4.2
unnamed: R12.1, U5.2
unnamed: R13.1, U4.3
unnamed: R14.1, U5.3
unnamed: R15.1, U6.2
unnamed: R16.1, U6.3
unnamed: R17.1, U7.2
unnamed: R18.1, U8.2
unnamed: R19.1, U9.2
unnamed: R20.2, U7.6
unnamed: R21.2, U8.6
unnamed: R22.2, U9.6
unnamed: R23.1, U10.2
unnamed: R24.1, U11.2
unnamed: R25.2, U10.6
unnamed: R26.2, U11.6

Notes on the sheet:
TERMINALES SALIDAS 220VAC/24VDC
Salidas Digitales
hfe=35 (min) Ic (max) = 0.8A
Rrele= 70 ohm

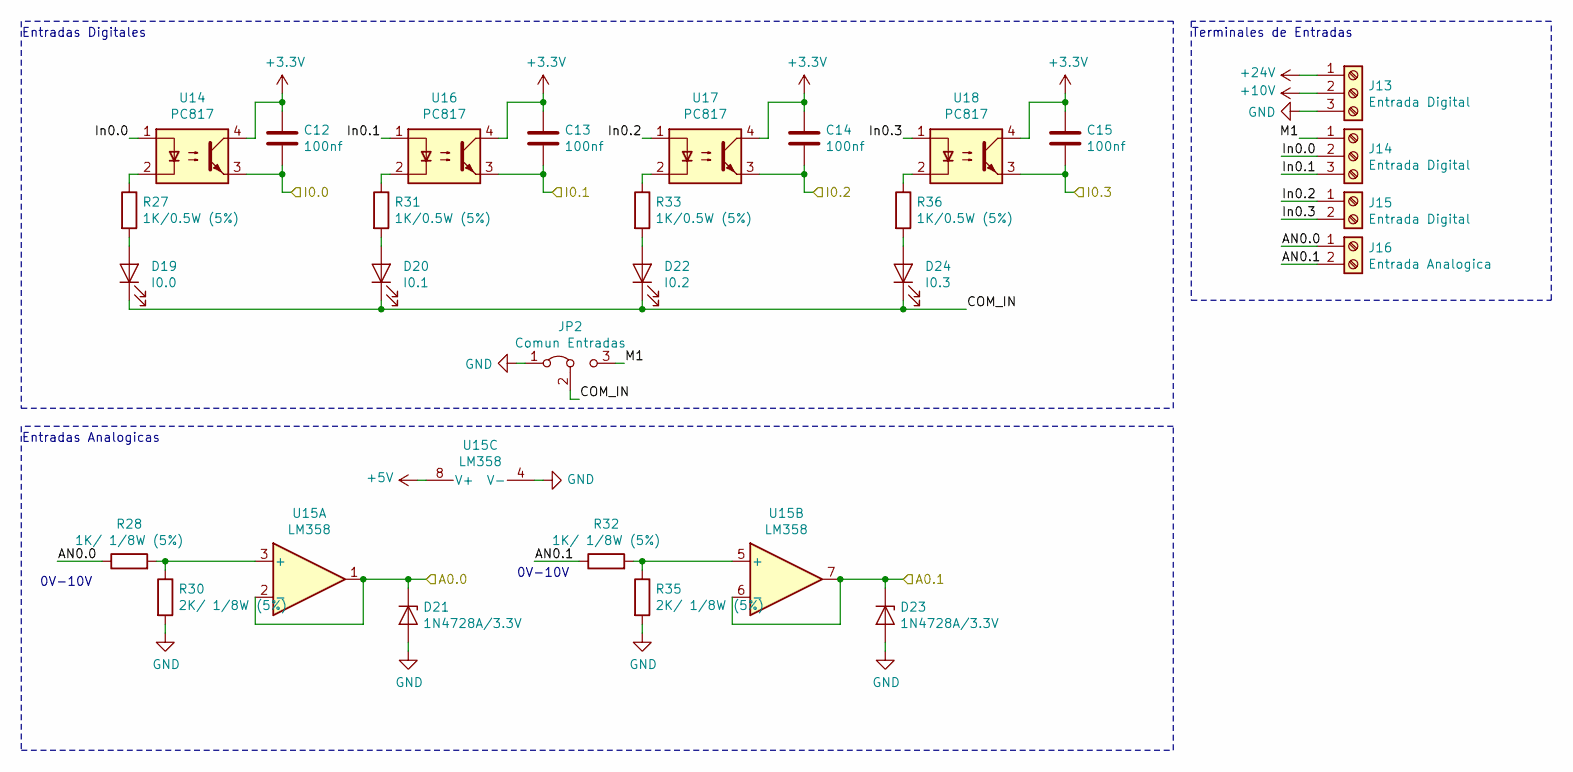
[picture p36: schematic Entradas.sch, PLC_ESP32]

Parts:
C12, C13, C14, C15: 100nf; C_0805_2012Metric
D19: I0.0; LED_0805_2012Metric
D20: I0.1; LED_0805_2012Metric
D21, D23: 1N4728A/3.3V; D_DO-41_SOD81_P10.16mm_Horizontal
D22: I0.2; LED_0805_2012Metric
D24: I0.3; LED_0805_2012Metric
J13, J14: Entrada Digital; TerminalBlock_Phoenix_PT-1,5-3-5.0-H_1x03_P5.00mm_Horizontal
J15: Entrada Digital; TerminalBlock_Phoenix_PT-1,5-2-5.0-H_1x02_P5.00mm_Horizontal
J16: Entrada Analogica; TerminalBlock_Phoenix_PT-1,5-2-5.0-H_1x02_P5.00mm_Horizontal
JP2: Comun Entradas; PinHeader_1x03_P2.54mm_Vertical
R27, R31, R33, R36: 1K/0.5W (5%); R_Axial_DIN0207_L6.3mm_D2.5mm_P10.16mm_Horizontal
R28, R32: 1K/ 1/8W (5%); R_0805_2012Metric
R30, R35: 2K/ 1/8W (5%); R_0805_2012Metric
U14, U16, U17, U18: PC817; DIP-4_W7.62mm_LongPads
U15: LM358; SOIC-8_3.9x4.9mm_P1.27mm

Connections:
+3V3: C12.1, C13.1, C14.1, C15.1, U14.4, U16.4, U17.4, U18.4; also elsewhere on the board
+5V: U15.8 (V+); also elsewhere on the board
+10V: J13.2; also elsewhere on the board
+24V: J13.1; also elsewhere on the board
/Control/A0.0: D21.1 (K), U15.1, U15.2 (-); also elsewhere on the board
/Control/A0.1: D23.1 (K), U15.6 (-), U15.7; also elsewhere on the board
/Control/I0.0: C12.2, U14.3; also elsewhere on the board
/Control/I0.1: C13.2, U16.3; also elsewhere on the board
/Control/I0.2: C14.2, U17.3; also elsewhere on the board
/Control/I0.3: C15.2, U18.3; also elsewhere on the board
/Entradas/AN0.0: J16.1, R28.1
/Entradas/AN0.1: J16.2, R32.1
/Entradas/COM_IN: D19.1 (K), D20.1 (K), D22.1 (K), D24.1 (K), JP2.2 (C)
/Entradas/In0.0: J14.2, U14.1
/Entradas/In0.1: J14.3, U16.1
/Entradas/In0.2: J15.1, U17.1
/Entradas/In0.3: J15.2, U18.1
/Entradas/M1: J14.1, JP2.3 (B)
GND: D21.2 (A), D23.2 (A), J13.3, JP2.1 (A), R30.2, R35.2, U15.4 (V-); also elsewhere on the board
unnamed: D19.2 (A), R27.2
unnamed: D20.2 (A), R31.2
unnamed: D22.2 (A), R33.2
unnamed: D24.2 (A), R36.2
unnamed: R27.1, U14.2
unnamed: R28.2, R30.1, U15.3 (+)
unnamed: R31.1, U16.2
unnamed: R32.2, R35.1, U15.5 (+)
unnamed: R33.1, U17.2
unnamed: R36.1, U18.2

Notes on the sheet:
Entradas Digitales
Entradas Analogicas
Terminales de Entradas
0V-10V

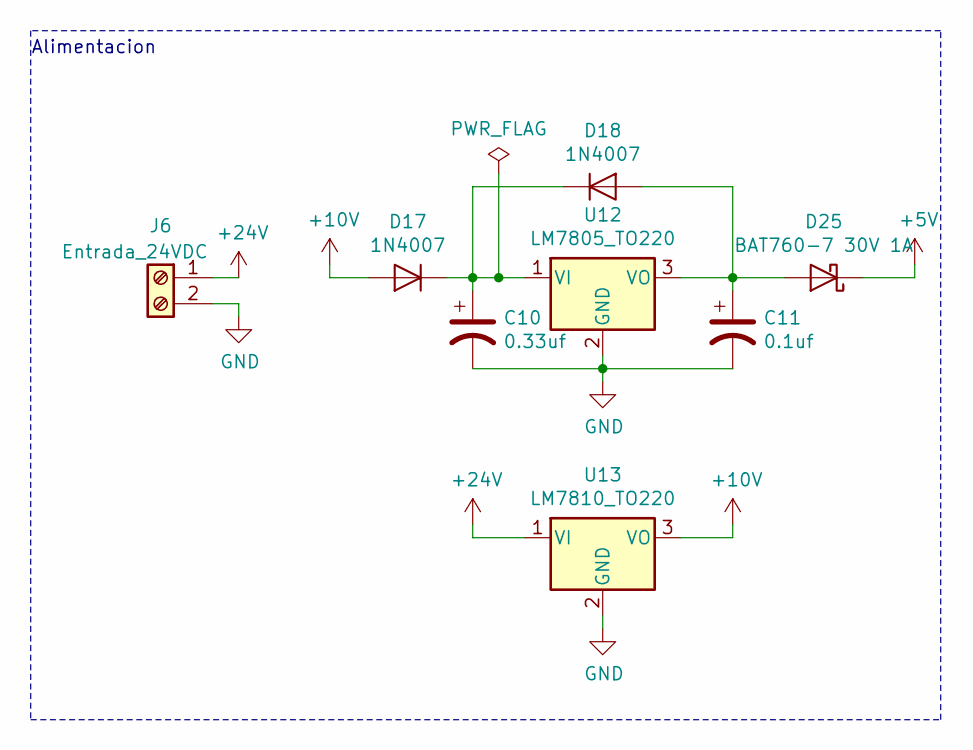
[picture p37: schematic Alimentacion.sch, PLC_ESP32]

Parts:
C10: 0.33uf; CP_Radial_D5.0mm_P2.00mm
C11: 0.1uf; CP_Radial_D5.0mm_P2.00mm
D17, D18: 1N4007; D_SMA
D25: BAT760-7 30V 1A; D_DO-41_SOD81_P10.16mm_Horizontal
J6: Entrada_24VDC; TerminalBlock_Phoenix_PT-1,5-2-5.0-H_1x02_P5.00mm_Horizontal
U12: LM7805_TO220; TO-220-3_Horizontal_TabUp
U13: LM7810_TO220; TO-220-3_Horizontal_TabUp

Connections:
+5V: D25.1 (K); also elsewhere on the board
+10V: D17.2 (A), U13.3 (VO); also elsewhere on the board
+24V: J6.1, U13.1 (VI); also elsewhere on the board
GND: C10.2, C11.2, J6.2, U12.2 (GND), U13.2 (GND); also elsewhere on the board
unnamed: C10.1, D17.1 (K), D18.1 (K), U12.1 (VI)
unnamed: C11.1, D18.2 (A), D25.2 (A), U12.3 (VO)

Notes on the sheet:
Alimentacion

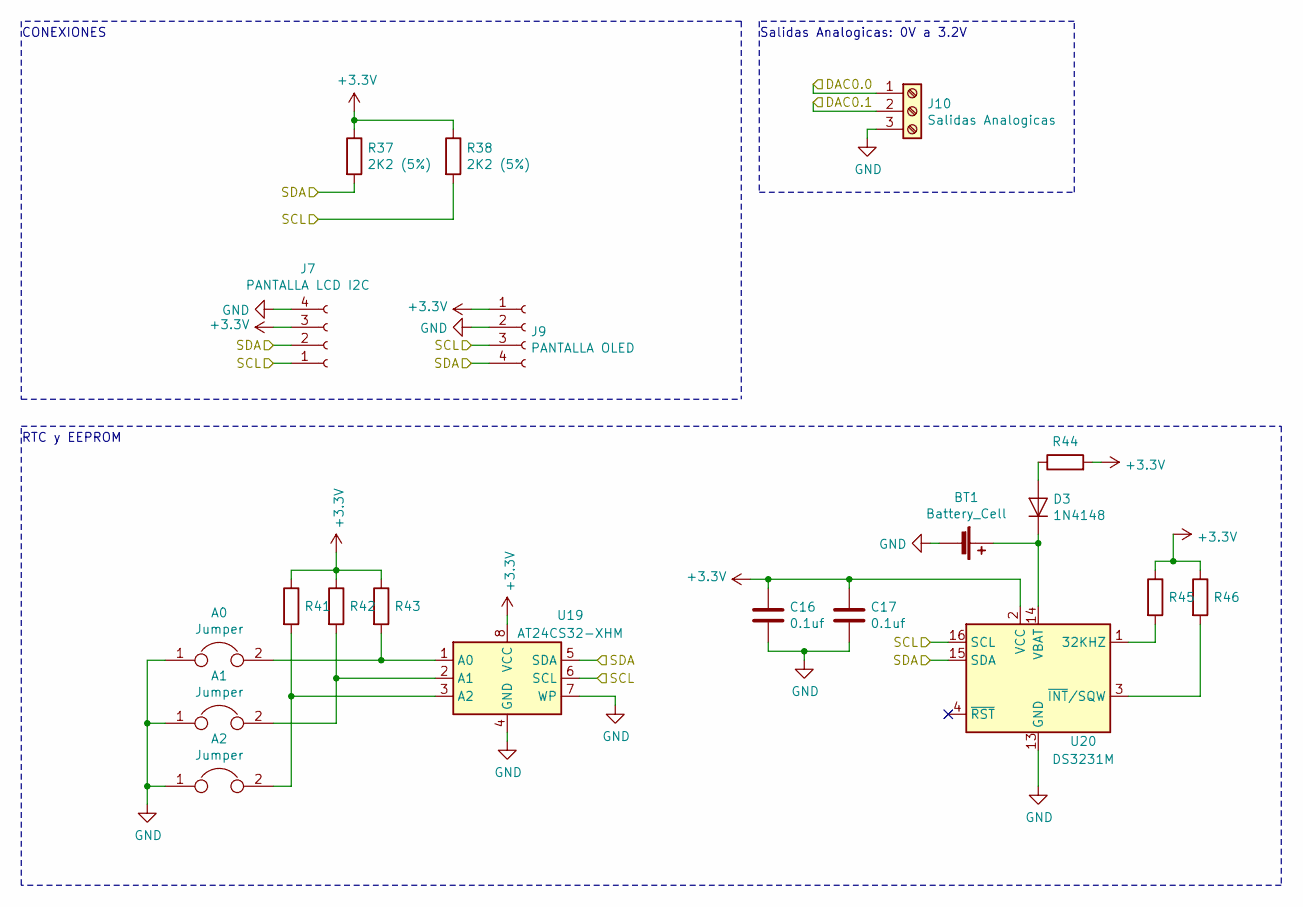
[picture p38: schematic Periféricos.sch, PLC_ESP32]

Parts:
A0, A1, A2: Jumper; SolderJumper-2_P1.3mm_Open_Pad1.0x1.5mm
BT1: Battery_Cell; BatteryHolder_Keystone_103_1x20mm
C16, C17: 0.1uf; C_0805_2012Metric
D3: 1N4148; D_MELF
J7: PANTALLA LCD I2C; PinSocket_1x04_P2.54mm_Horizontal
J9: PANTALLA OLED; 128x64OLED
J10: Salidas Analogicas; TerminalBlock_Phoenix_PT-1,5-3-5.0-H_1x03_P5.00mm_Horizontal
R37, R38: 2K2 (5%); R_0805_2012Metric
R41, R42, R43, R45, R46: 4K7 1/8W 5%; R_0805_2012Metric
R44: 200 1/8W 5%; R_0805_2012Metric
U19: AT24CS32-XHM; TSSOP-8_4.4x3mm_P0.65mm
U20: DS3231M; SOIC-16W_7.5x10.3mm_P1.27mm

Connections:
+3V3: C16.1, C17.1, J7.3, J9.1, R37.1, R38.1, R41.1, R42.1, R43.1, R44.2, R45.1, R46.1, U19.8 (VCC), U20.2 (VCC); also elsewhere on the board
/Control/DAC0.0: J10.1; also elsewhere on the board
/Control/DAC0.1: J10.2; also elsewhere on the board
/Control/SCL: J7.1, J9.3, R38.2, U19.6 (SCL), U20.16 (SCL); also elsewhere on the board
/Control/SDA: J7.2, J9.4, R37.2, U19.5 (SDA), U20.15 (SDA); also elsewhere on the board
GND: A0.1, A1.1, A2.1, BT1.2 (-), C16.2, C17.2, J7.4, J9.2, J10.3, U19.4 (GND), U19.7 (WP), U20.5 (GND), U20.6 (GND), U20.7 (GND), U20.8 (GND), U20.9 (GND), U20.10 (GND), U20.11 (GND), U20.12 (GND), U20.13 (GND); also elsewhere on the board
unnamed: A0.2, R43.2, U19.1 (A0)
unnamed: A1.2, R42.2, U19.2 (A1)
unnamed: A2.2, R41.2, U19.3 (A2)
unnamed: BT1.1 (+), D3.1 (K), U20.14 (VBAT)
unnamed: D3.2 (A), R44.1
unnamed: R45.2, U20.1 (32KHZ)
unnamed: R46.2, U20.3 (~INT~/SQW)

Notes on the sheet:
CONEXIONES
Salidas Analogicas: 0V a 3.2V
RTC y EEPROM

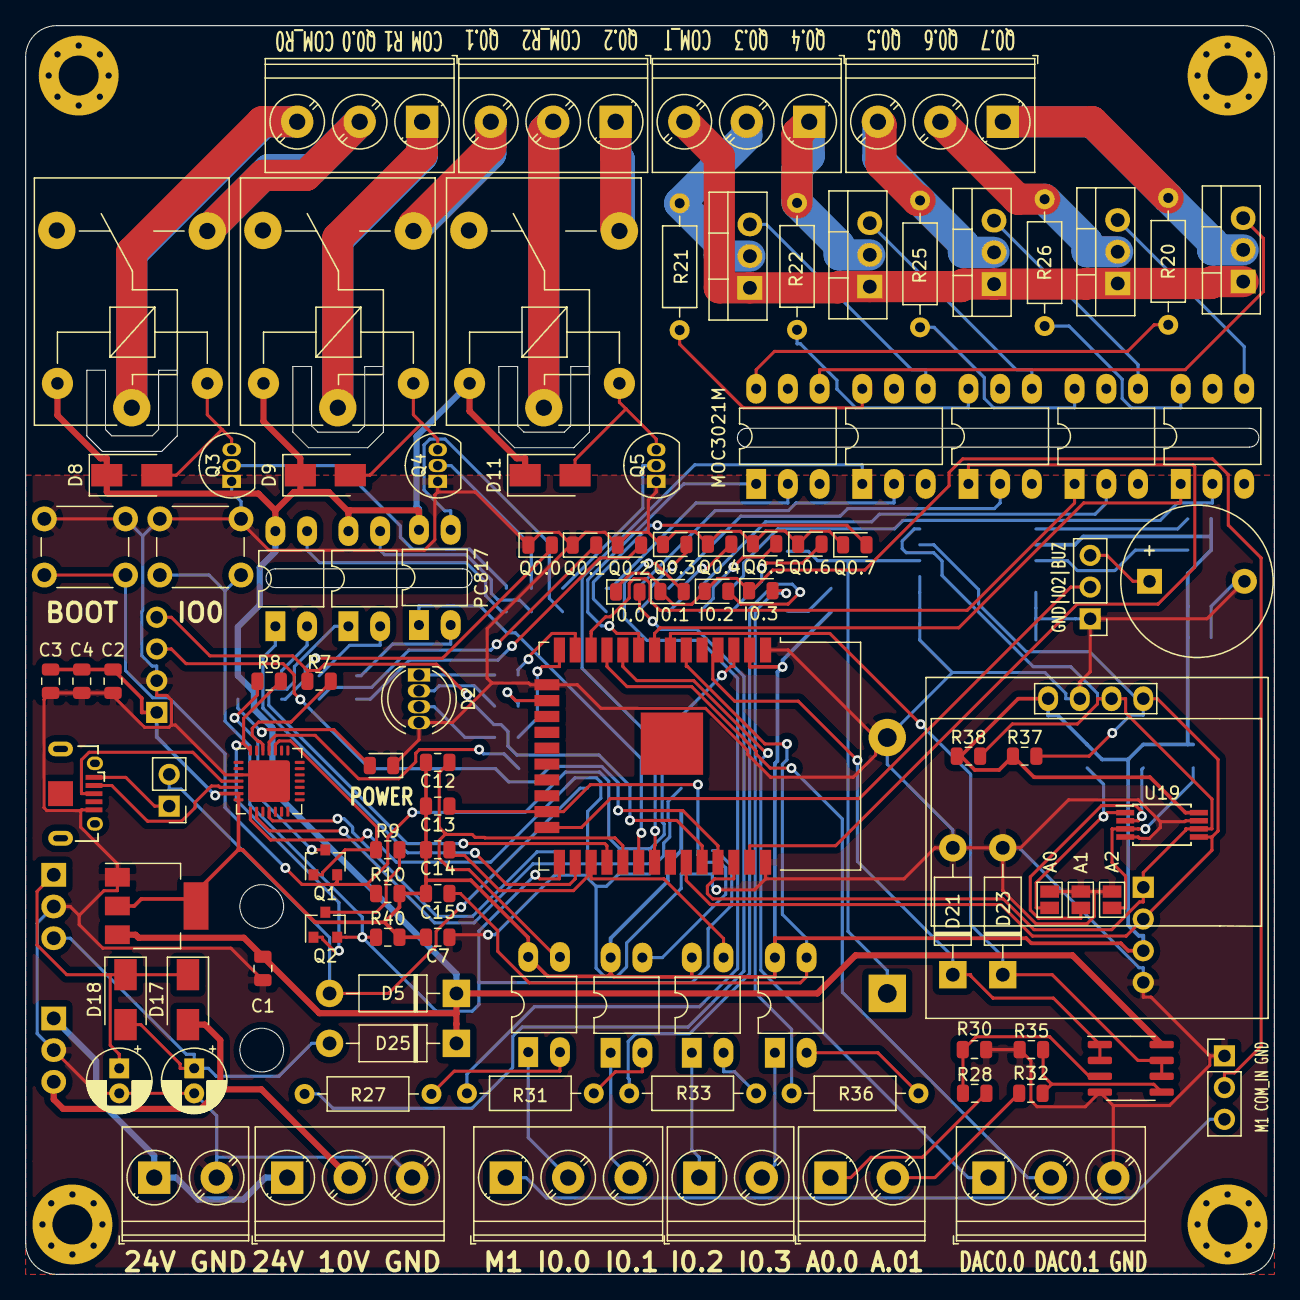
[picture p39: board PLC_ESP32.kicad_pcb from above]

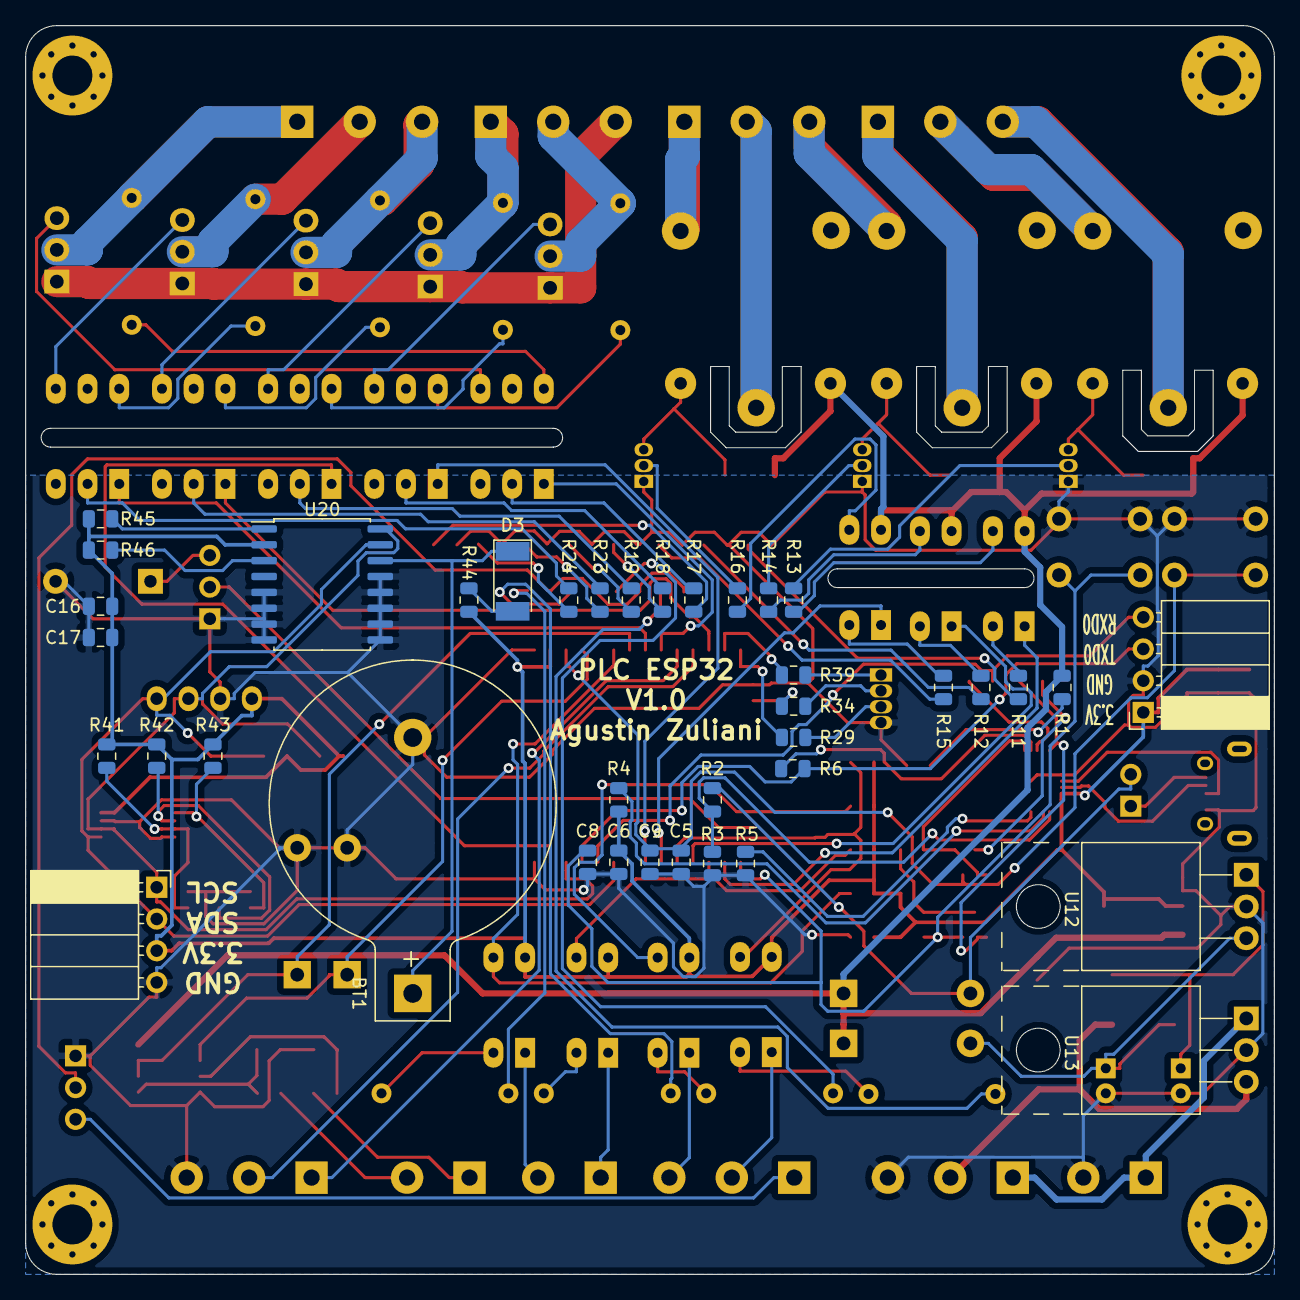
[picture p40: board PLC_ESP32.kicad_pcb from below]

Board: 2 copper layers, 100.0 x 100.0 mm, 148 parts (39 on the bottom side), 123 nets.

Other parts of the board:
REF1, REF1#2, REF1#3, REF1#4: MountingHole_3.2mm_M3_Pad_Via

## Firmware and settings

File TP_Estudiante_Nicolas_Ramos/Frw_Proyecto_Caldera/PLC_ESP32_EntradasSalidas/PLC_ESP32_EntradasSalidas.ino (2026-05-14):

// ----- Solo declaración e inicialización de entradas y salidas -----
#include <Wire.h>
#include <Adafruit_GFX.h>
#include <Adafruit_SH110X.h>

#define ANCHO  128
#define ALTO   64
#define DIR_OLED  0x3C
#define OLED_SDA  21
#define OLED_SCL  22

Adafruit_SH1106G oled(ANCHO, ALTO, &Wire, -1);

#define I0_0  5
#define I0_1  15
#define I0_2  16
#define I0_3  34

#define Q0_0  4
#define Q0_1  17
#define Q0_2  18
#define Q0_3  19
#define Q0_4  23
#define Q0_5  27
#define Q0_6  32
#define Q0_7  33

#define A0_0  36   // AN0.0 (VP)
#define A0_1  35   // AN0.1 (VN)
#define DAC0_0  25
#define DAC0_1  26

// LED RGB (D2 LED_RGBC): común a GND, R=IO14, G=IO13, B=IO12
#define RGB_R  14
#define RGB_G  13
#define RGB_B  12

#define TIEMPO_MS  700
#define SERIAL_ANALOG_MS  500
#define RGB_MS  800

const uint8_t salidas[] = { Q0_0, Q0_1, Q0_2, Q0_3, Q0_4, Q0_5, Q0_6, Q0_7 };
const int N = 8;

int indice = 0;
unsigned long lastStep = 0;
unsigned long lastAnalog = 0;
unsigned long lastRgb = 0;
int rgbEstado = 0;  // 0=R, 1=G, 2=B, 3=Amarillo, 4=Cian, 5=Magenta, 6=Blanco, 7=Apagado

void setup() {
  pinMode(I0_0, INPUT_PULLDOWN);
  pinMode(I0_1, INPUT_PULLDOWN);
  pinMode(I0_2, INPUT_PULLDOWN);
  pinMode(I0_3, INPUT);  // R externa a masa

  pinMode(Q0_0, OUTPUT);
  pinMode(Q0_1, OUTPUT);
  pinMode(Q0_2, OUTPUT);
  pinMode(Q0_3, OUTPUT);
  pinMode(Q0_4, OUTPUT);
  pinMode(Q0_5, OUTPUT);
  pinMode(Q0_6, OUTPUT);
  pinMode(Q0_7, OUTPUT);

  digitalWrite(Q0_0, LOW);
  digitalWrite(Q0_1, LOW);
  digitalWrite(Q0_2, LOW);
  digitalWrite(Q0_3, LOW);
  digitalWrite(Q0_4, LOW);
  digitalWrite(Q0_5, LOW);
  digitalWrite(Q0_6, LOW);
  digitalWrite(Q0_7, LOW);

  pinMode(RGB_R, OUTPUT);
  pinMode(RGB_G, OUTPUT);
  pinMode(RGB_B, OUTPUT);
  digitalWrite(RGB_R, LOW);
  digitalWrite(RGB_G, LOW);
  digitalWrite(RGB_B, LOW);

  Serial.begin(115200);
  // DAC: 1.2V -> 1.2/3.3*255 ≈ 93,  3V -> 3.0/3.3*255 ≈ 232
  dacWrite(DAC0_0, (uint8_t)(255.0 * 1.2 / 3.3));
  dacWrite(DAC0_1, (uint8_t)(255.0 * 3.0 / 3.3));

  Wire.begin(OLED_SDA, OLED_SCL);
  Wire.setClock(100000);
  delay(200);
  if (oled.begin(DIR_OLED, true) || oled.begin(0x3D, true)) {
    oled.clearDisplay();
    oled.setTextSize(2);
    oled.setTextColor(SH110X_WHITE);
    oled.setCursor(20, 24);
    oled.print("hola man");
    oled.display();
  }
}

void loop() {
  // Con cualquier I0.x en tensión (pin lee HIGH) se hace toggle Q0.0 -> Q0.7 cada 700 ms
  bool activo = (digitalRead(I0_0) == HIGH || digitalRead(I0_1) == HIGH ||
                digitalRead(I0_2) == HIGH || digitalRead(I0_3) == HIGH);

  if (activo) {
    if (lastStep == 0) {
      for (int i = 0; i < N; i++)
        digitalWrite(salidas[i], LOW);
      indice = 0;
      digitalWrite(salidas[0], HIGH);
      lastStep = millis();
    }
    if (millis() - lastStep >= TIEMPO_MS) {
      digitalWrite(salidas[indice], LOW);
      indice = (indice + 1) % N;
      digitalWrite(salidas[indice], HIGH);
      lastStep = millis();
    }
  } else {
    for (int i = 0; i < N; i++)
      digitalWrite(salidas[i], LOW);
    indice = 0;
    lastStep = 0;
  }

  if (millis() - lastAnalog >= SERIAL_ANALOG_MS) {
    lastAnalog = millis();
    int v0 = analogRead(A0_0);
    int v1 = analogRead(A0_1);
    Serial.print("AN0.0=");
    Serial.print(v0);
    Serial.print("  AN0.1=");
    Serial.println(v1);
  }

  // LED RGB: ciclo R -> G -> B -> Amarillo -> Cian -> Magenta -> Blanco -> Apagado
  if (millis() - lastRgb >= RGB_MS) {
    lastRgb = millis();
    digitalWrite(RGB_R, (rgbEstado == 0 || rgbEstado == 3 || rgbEstado == 5 || rgbEstado == 6) ? HIGH : LOW);
    digitalWrite(RGB_G, (rgbEstado == 1 || rgbEstado == 3 || rgbEstado == 4 || rgbEstado == 6) ? HIGH : LOW);
    digitalWrite(RGB_B, (rgbEstado == 2 || rgbEstado == 4 || rgbEstado == 5 || rgbEstado == 6) ? HIGH : LOW);
    rgbEstado = (rgbEstado + 1) % 8;
  }
}

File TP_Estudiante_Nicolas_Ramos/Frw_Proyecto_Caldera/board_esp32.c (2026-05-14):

/**
 * @file board_esp32.c
 * @brief Plantilla PLC_ESP32: definiciones y configuración de GPIO.
 */

#include "board_esp32.h"

#ifdef ESP_PLATFORM
#include "driver/gpio.h"
#include "esp_adc/adc_oneshot.h"
#include "esp_adc/adc_cali.h"
#include "esp_adc/adc_cali_scheme.h"
#include "driver/dac.h"
#endif

/* Array de salidas digitales en orden Q0.0 .. Q0.7 */
const uint8_t board_esp32_salidas_dig[NUM_Q0] = {
    Q0_0, Q0_1, Q0_2, Q0_3, Q0_4, Q0_5, Q0_6, Q0_7
};

#ifdef ESP_PLATFORM
static adc_oneshot_unit_handle_t adc1_handle = NULL;
static adc_cali_handle_t adc1_cali_a0 = NULL;
#endif

void board_esp32_init(void)
{
#ifdef ESP_PLATFORM
    gpio_config_t io = {
        .pin_bit_mask   = 0,
        .mode           = GPIO_MODE_OUTPUT,
        .pull_up_en     = GPIO_PULLUP_DISABLE,
        .pull_down_en   = GPIO_PULLDOWN_DISABLE,
        .intr_type      = GPIO_INTR_DISABLE,
    };

    /* Entradas digitales I0.0, I0.1, I0.2 (pull-down), I0.3 (sin pull) */
    gpio_config_t in_pulldown = {
        .mode           = GPIO_MODE_INPUT,
        .pull_up_en     = GPIO_PULLUP_DISABLE,
        .pull_down_en   = GPIO_PULLDOWN_ENABLE,
        .intr_type      = GPIO_INTR_DISABLE,
    };
    in_pulldown.pin_bit_mask = (1ULL << I0_0) | (1ULL << I0_1) | (1ULL << I0_2);
    gpio_config(&in_pulldown);

    gpio_config_t in_float = {
        .mode           = GPIO_MODE_INPUT,
        .pull_up_en     = GPIO_PULLUP_DISABLE,
        .pull_down_en   = GPIO_PULLDOWN_DISABLE,
        .intr_type      = GPIO_INTR_DISABLE,
    };
    in_float.pin_bit_mask = (1ULL << I0_3);
    gpio_config(&in_float);

    /* Salidas digitales Q0.0 .. Q0.7 */
    io.pin_bit_mask = (1ULL << Q0_0) | (1ULL << Q0_1) | (1ULL << Q0_2) | (1ULL << Q0_3)
                    | (1ULL << Q0_4) | (1ULL << Q0_5) | (1ULL << Q0_6) | (1ULL << Q0_7);
    gpio_config(&io);
    for (int i = 0; i < NUM_Q0; i++)
        gpio_set_level(board_esp32_salidas_dig[i], 0);

    /* Buzzer */
    io.pin_bit_mask = (1ULL << BUZZER);
    gpio_config(&io);
    gpio_set_level(BUZZER, 0);

    /* LED RGB */
    io.pin_bit_mask = (1ULL << RGB_R) | (1ULL << RGB_G) | (1ULL << RGB_B);
    gpio_config(&io);
    gpio_set_level(RGB_R, 0);
    gpio_set_level(RGB_G, 0);
    gpio_set_level(RGB_B, 0);

    /* Entradas analógicas A0.0 (GPIO 36), A0.1 (GPIO 35): ADC1 oneshot (ESP-IDF 5.x) */
    adc_oneshot_unit_init_cfg_t adc_cfg = {
        .unit_id = ADC_UNIT_1,
        .ulp_mode = ADC_ULP_MODE_DISABLE,
    };
    esp_err_t err = adc_oneshot_new_unit(&adc_cfg, &adc1_handle);
    if (err != ESP_OK) {
        adc1_handle = NULL;
    } else {
        adc_oneshot_chan_cfg_t ch_cfg = {
            .atten = ADC_ATTEN_DB_11,
            .bitwidth = ADC_BITWIDTH_12,
        };
        adc_oneshot_config_channel(adc1_handle, ADC_CHANNEL_0, &ch_cfg);  /* A0_0 */
        adc_oneshot_config_channel(adc1_handle, ADC_CHANNEL_7, &ch_cfg);   /* A0_1 */

        adc_cali_line_fitting_config_t cali_cfg = {
            .unit_id = ADC_UNIT_1,
            .atten = ADC_ATTEN_DB_11,
            .bitwidth = ADC_BITWIDTH_12,
        };
        if (adc_cali_create_scheme_line_fitting(&cali_cfg, &adc1_cali_a0) != ESP_OK)
            adc1_cali_a0 = NULL;
    }

    /* Salidas DAC0.0 (GPIO 25), DAC0.1 (GPIO 26) */
    dac_output_enable(DAC_CHANNEL_1);  /* DAC0_0 = GPIO 25 */
    dac_output_enable(DAC_CHANNEL_2);  /* DAC0_1 = GPIO 26 */
    dac_output_voltage(DAC_CHANNEL_1, 0);
    dac_output_voltage(DAC_CHANNEL_2, 0);
#endif
}

#ifdef ESP_PLATFORM
int board_esp32_adc_a0_0_raw(void)
{
    if (adc1_handle == NULL) return -1;
    int raw = 0;
    if (adc_oneshot_read(adc1_handle, ADC_CHANNEL_0, &raw) != ESP_OK)
        return -1;
    return raw;
}

int board_esp32_adc_a0_0_mv(void)
{
    if (adc1_handle == NULL) return -1;
    int raw = 0;
    if (adc_oneshot_read(adc1_handle, ADC_CHANNEL_0, &raw) != ESP_OK)
        return -1;
    if (adc1_cali_a0 != NULL) {
        int mv = 0;
        if (adc_cali_raw_to_voltage(adc1_cali_a0, raw, &mv) == ESP_OK)
            return mv;
    }
    return (int)((float)raw * 2450.0f / 4095.0f + 0.5f);
}
#endif

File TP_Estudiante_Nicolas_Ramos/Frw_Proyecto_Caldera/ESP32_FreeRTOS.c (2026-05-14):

/**
 * @file ESP32_FreeRTOS.c
 * @brief Control de temperatura con FreeRTOS.
 *        LM35 0–150 °C → 0–1,5 V en AN0.0; divisor R28/R30 (2/3) → 0–1,0 V en A0.0; escala °C = 150·(V_pin/1V).
 *        I0.0 = sensor presión (5V/0V). Q0.0 = calefacción, Q0.1 = cooler.
 *        Setpoint por UART0 (USB): línea con Enter, 1–2 dígitos (0–99).
 *        Alarma: Q0.0 off, Q0.1 on, buzzer toggle 500 ms; 2 s sin I0.0 activo → normal.
 *        Calefacción con histéresis ±1 °C alrededor del setpoint (menos conmutaciones).
 */

#include "board_esp32.h"
#include "oled_display.h"
#include "control_state.h"
#include "web_ui.h"
#include "freertos/FreeRTOS.h"
#include "freertos/task.h"
#include "freertos/queue.h"
#include "freertos/semphr.h"
#include "driver/gpio.h"
#include "driver/uart.h"
#include "esp_err.h"
#include <stdbool.h>
#include <stdio.h>

/* Prioridades: mayor número = mayor prioridad en el planificador FreeRTOS */
#define PRIO_CONTROL  5
#define PRIO_ADC      4
#define PRIO_UART     3
#define PRIO_DISPLAY  2

#define SETPOINT_QUEUE_LEN  4
#define SETPOINT_DEFAULT    25
#define ALARMA_TIEMPO_MS    2000
#define BUZZER_TOGGLE_MS    500
#define STACK_TASK          2048

/* Enciende si T < SP - HYST; apaga si T > SP + HYST; entre medias mantiene el estado anterior */
#define HYSTERESIS_TEMP_C  1.0f

/* 1 = sobrepresión con I0.0 en alto (5 V, informe). 0 = activo en bajo (contacto a masa / NPN). */
#define PRESION_I0_ACTIVO_NIVEL_ALTO  1

/* Acondicionamiento: V_pin = V_AN0.0 · R30/(R28+R30) = V_AN0.0 · 2/3.
 * LM35 máx. 1,5 V → V_pin máx. 1,0 V. T(°C) = T_max · (V_pin / 1 V). */
#define LM35_TEMP_MAX_C   150.0f
#define LM35_PIN_MV_MAX   1000.0f   /* 1,5 V LM35 × 2/3 en el pin A0.0 */
#define LM35_PIN_MV_TRIM  1.0f      /* Ganancia fina si la lectura no calza con multímetro */
#define LM35_OFFSET_C     0.0f      /* Corrección de offset en °C */
#define LM35_ADC_SAMPLES  4         /* Promedio de lecturas para reducir ruido ADC */

/* Estado global: control_state.c (g_control_estado + g_control_mutex) */
static QueueHandle_t queue_setpoint;

/* Convierte mV en A0.0 (board_esp32_adc_a0_0_mv, calibrado) a °C según escala 0–1 V → 0–150 °C */
static float leer_temperatura_lm35(void)
{
    int acc = 0, n = 0;
    for (int i = 0; i < LM35_ADC_SAMPLES; i++) {
        int mv = board_esp32_adc_a0_0_mv();
        if (mv >= 0) {
            acc += mv;
            n++;
        }
    }
    if (n == 0) return 0.0f;
    float mv_pin = LM35_PIN_MV_TRIM * (float)acc / (float)n;
    return (mv_pin / LM35_PIN_MV_MAX) * LM35_TEMP_MAX_C + LM35_OFFSET_C;
}

/* Cada 200 ms muestrea LM35 y actualiza estado.temp_c bajo mutex */
static void task_adc(void *pvParameters)
{
    for (;;) {
        float t = leer_temperatura_lm35();
        if (xSemaphoreTake(g_control_mutex, pdMS_TO_TICKS(50)) == pdTRUE) {
            g_control_estado.temp_c = t;
            xSemaphoreGive(g_control_mutex);
        }
        vTaskDelay(pdMS_TO_TICKS(200));
    }
}

/* UART0 (USB): TX GPIO1, RX GPIO3 — mismo puerto que el monitor; setpoint línea + Enter */
#define UART_SETPOINT_NUM   UART_NUM_0
#define UART_SETPOINT_TX    1
#define UART_SETPOINT_RX    3
#define UART_BAUD           115200
#define UART_BUF            256

/* Lee el setpoint carácter a carácter: el USB envía dígitos sueltos y \r\n; leer 2 bytes de golpe falla a menudo */
static void task_uart(void *pvParameters)
{
    uint8_t line[12];
    size_t len = 0;

    for (;;) {
        uint8_t c;
        int n = uart_read_bytes(UART_SETPOINT_NUM, &c, 1, portMAX_DELAY);
        if (n <= 0)
            continue;

        if (c == '\r' || c == '\n') {
            int setpoint = -1;
            if (len == 1 && line[0] >= '0' && line[0] <= '9')
                setpoint = line[0] - '0';
            else if (len >= 2 && line[0] >= '0' && line[0] <= '9' && line[1] >= '0' && line[1] <= '9')
                setpoint = (line[0] - '0') * 10 + (line[1] - '0');
            len = 0;
            if (setpoint >= 0) {
                if (setpoint > 99)
                    setpoint = 99;
                (void)xQueueSend(queue_setpoint, &setpoint, pdMS_TO_TICKS(50));
            }
            continue;
        }

        if (len < sizeof(line) - 1)
            line[len++] = c;
        else
            len = 0;
    }
}

/* Prioridad máxima: cola setpoint, lógica alarma I0.0, T vs SP → Q0.0/Q0.1, buzzer en alarma */
static void task_control(void *pvParameters)
{
    int setpoint_local = SETPOINT_DEFAULT;
    int nuevo_setpoint;
    TickType_t now;
    static TickType_t buzz_last_toggle = 0;
    static int buzz_level = 0;
    /* Memoria de la histéresis: entre SP−HYST y SP+HYST no cambia el pedido de calefacción */
    static bool retencion_calefactor = false;

    for (;;) {
        now = xTaskGetTickCount();

        if (xQueueReceive(queue_setpoint, &nuevo_setpoint, 0) == pdTRUE)
            setpoint_local = nuevo_setpoint;

        /* portMAX_DELAY: evita saltar el ciclo sin escribir Q0.x si el mutex no se obtiene a tiempo */
        xSemaphoreTake(g_control_mutex, portMAX_DELAY);

        int sp = setpoint_local;
        float temp = g_control_estado.temp_c;
        int i0_pin = gpio_get_level(I0_0);
        bool i0_high = PRESION_I0_ACTIVO_NIVEL_ALTO ? (i0_pin == 1) : (i0_pin == 0);

        if (i0_high) {
            g_control_estado.alarm_active = true;
            g_control_estado.alarm_low_since_ticks = 0;
        } else if (g_control_estado.alarm_active) {
            /* Salir de alarma solo tras ALARMA_TIEMPO_MS con I0.0 en bajo */
            if (g_control_estado.alarm_low_since_ticks == 0)
                g_control_estado.alarm_low_since_ticks = now;
            if ((now - g_control_estado.alarm_low_since_ticks) >= pdMS_TO_TICKS(ALARMA_TIEMPO_MS))
                g_control_estado.alarm_active = false;
        } else {
            g_control_estado.alarm_low_since_ticks = 0;
        }
        bool alarm = g_control_estado.alarm_active;
        g_control_estado.setpoint = setpoint_local;  /* Para el OLED y la web */

        if (alarm) {
            retencion_calefactor = false;
        } else {
            float sp_f = (float)sp;
            if (temp < sp_f - HYSTERESIS_TEMP_C)
                retencion_calefactor = true;
            else if (temp > sp_f + HYSTERESIS_TEMP_C)
                retencion_calefactor = false;
        }
        g_control_estado.calefactor_on = retencion_calefactor;
        g_control_estado.sensor_sobrepresion = i0_high;

        xSemaphoreGive(g_control_mutex);
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

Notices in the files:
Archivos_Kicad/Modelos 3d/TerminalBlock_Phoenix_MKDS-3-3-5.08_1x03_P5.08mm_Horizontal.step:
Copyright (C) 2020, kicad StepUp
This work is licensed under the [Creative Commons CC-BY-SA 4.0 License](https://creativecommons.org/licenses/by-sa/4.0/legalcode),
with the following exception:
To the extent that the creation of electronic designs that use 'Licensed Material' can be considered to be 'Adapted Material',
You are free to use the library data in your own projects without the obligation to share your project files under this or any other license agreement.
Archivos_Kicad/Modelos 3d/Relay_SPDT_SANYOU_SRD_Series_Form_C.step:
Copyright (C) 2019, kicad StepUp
